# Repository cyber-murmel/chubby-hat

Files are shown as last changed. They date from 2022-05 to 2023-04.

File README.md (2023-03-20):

# Chubby Hat
A PCB that turns the [Colorlight 5A-75B](https://www.aliexpress.com/item/32728519290.html)
into an easy to use development platform for cheap.
This project ist based on [q3k/chubby75](https://github.com/q3k/chubby75/tree/master/5a-75b).

Read more on [ hackaday.io](https://hackaday.io/project/174032-chubby-hat).

## Directory Structure
| directory  | content |
|---|---|
| source | KiCad project directories |
| production | fabrication files (Gerber, BOM, placement) |
| exports | schematic and layout plots, board 3D model and renderings |
| datasheets | component datasheets |
| assets | board setups, component 3D models, logos |
| scripts | BOM export plugins, miscellaneous helper scripts for file conversion |
| hooks | git hooks, for example for automatic documentation export |

### Version 0.1.0

- USB to JTAG via STM32 or FTDI
- two 3x Pmod ports



### Version 0.2.0

- USB to JTAG via extra dev board or on-board RP2040
- three 2x Pmod ports

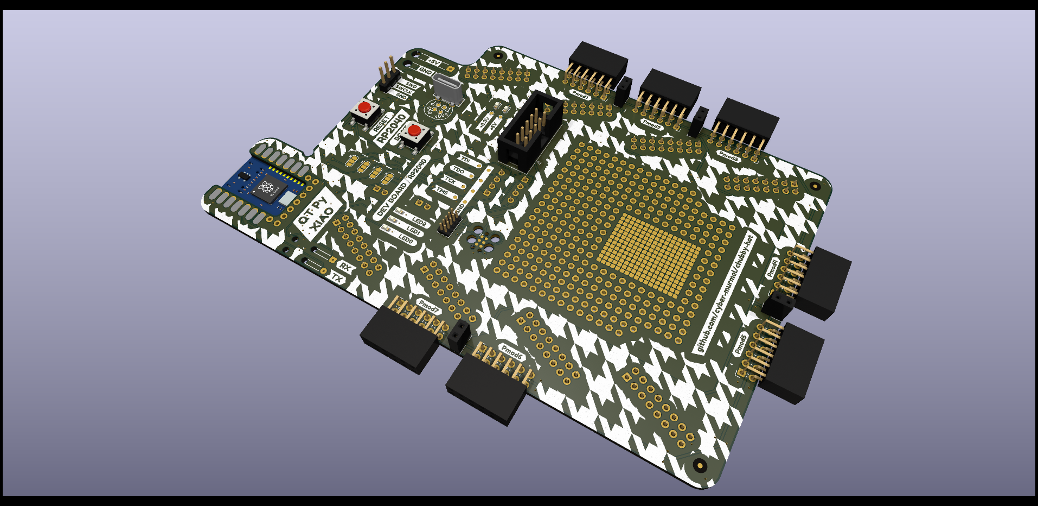
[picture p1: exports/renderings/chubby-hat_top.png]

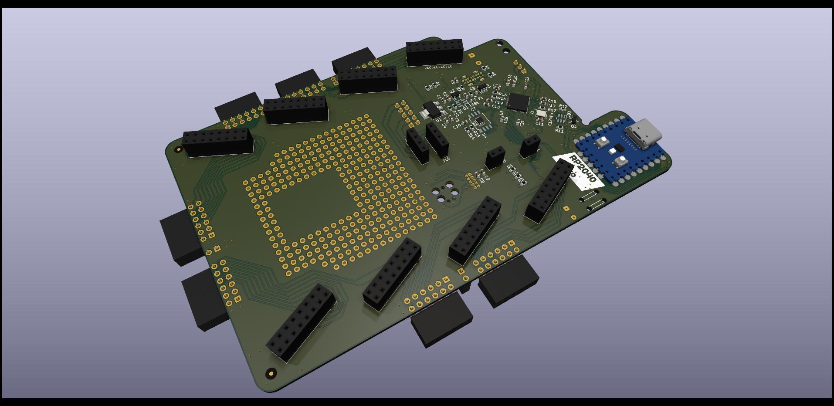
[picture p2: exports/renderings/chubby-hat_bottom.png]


## Automation
This repository contains a Makefile that automates PDF and Gerber export, as
well as PCB art pattern creation.

### Requirements
Apart from [KiCad 7](#kicad-version) this requires some additional software.

The Makefile calls a Python script that makes use of [sexptdata](https://pypi.org/project/sexpdata/) to parse KiCad files.
Install [Poetry](https://python-poetry.org/) and run `poetry shell` followed by `poetry install` in the root of this repositoryto set up a virtual environment with the required package(s). To re-enter this environment, simply run `poetry shell` in the root of this repository.

For PDF export you need to install [Poppler](https://poppler.freedesktop.org/).
Gerber export requires [zip](https://infozip.sourceforge.net/).
Pattern creation is implemented with [OpenSCAD](https://openscad.org/).

#### Nix(OS)
If you are using the Nix package manager, you can enter a development environment
with KiCad and all other software by running `nix-shell` in the root of this
repository.

### Export
To export all PDFs and Gerbers, simply run
```shell
make
```
PDFs and Gerbers are exported automatically when you `git commit`, if you have
[Git Hooks](#installing-git-hooks-optional) set up.

### Pattern
To recreate the pattern, first remove the pattern from the board and save it,
then run
```shell
make pattern
```
Add the new pattern graphic to the board.

### Installing Git Hooks (optional)
The [hooks](hooks) directory contains client-side [git hooks](https://git-scm.com/book/en/v2/Customizing-Git-Git-Hooks).
Currently only the pre-commit hook is used to automatically export plots.

To enable the hooks locally, run the following in the root of the repository.
```shell
git config core.hooksPath ./hooks
```

## KiCad Version
```
Version: 7.0.1, release build

Libraries:
	wxWidgets 3.2.2
	FreeType 2.12.1
	HarfBuzz 6.0.0
	FontConfig 2.14.0
	libcurl/7.87.0 OpenSSL/3.0.8 zlib/1.2.13 brotli/1.0.9 zstd/1.5.2 libidn2/2.3.2 libssh2/1.10.0 nghttp2/1.51.0

Platform: , 64 bit, Little endian, wxBase, , wayland

Build Info:
	Date: Jan  1 1980 00:00:00
	wxWidgets: 3.2.2 (wchar_t,wx containers) GTK+ 0.0
	Boost: 1.79.0
	OCC: 7.6.2
	Curl: 7.87.0
	ngspice: 37
	Compiler: GCC 12.2.0 with C++ ABI 1017

Build settings:
	KICAD_USE_EGL=ON
	KICAD_SPICE=ON
```

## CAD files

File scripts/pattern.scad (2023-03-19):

size = 2;
margin = 2;
dx = 170;
dy = 120;

edge = "";
mask = "";

module striped_square(size = 1, length = 1, num_stripes = 2) {
    color("teal")
        for(stripe = [1:num_stripes]) {
            if((stripe % 2) == 1) {
                polygon([[stripe-1, 0], [stripe,0], [0, stripe], [0,stripe-1]]*size/num_stripes);
            }
        }
    color("green")
        for(stripe = [num_stripes:length*num_stripes]) {
            if((stripe % 2) == 1) {
                polygon([[stripe-1, 0], [stripe,0], [stripe-num_stripes, num_stripes], [stripe-1-num_stripes,num_stripes]]*size/num_stripes);
            }
        }
    color("turquoise")
        for(stripe = [length*num_stripes:(length+1)*num_stripes]) {
            if((stripe % 2) == 1) {
                polygon([[length*num_stripes, stripe-length*num_stripes-1], [length*num_stripes,stripe-length*num_stripes], [stripe-num_stripes, num_stripes], [stripe-num_stripes-1,num_stripes]]*size/num_stripes);
            }
        }
}

module houndstooth(size = 1, dx = 2, dy = 2) {
    nx = ceil((dx/size) / 2);
    ny = ceil((dy/size) / 2);

    union() {
        for (y = [0: ny-1]) {
            translate(([0, y] * size * 2))
                striped_square(size, 2*nx, 2);
        }

        for (x = [0: nx-1]) {
            translate(
                ([x, 0] * size * 2)
              + ([1, 2*ny] * size)
            )
                mirror([1, 1])
                   striped_square(size, 2*ny, 2);
        }
    }
}

difference() {
    intersection() {
        translate([-25,-25]) {
            import(edge);
        }
        houndstooth(size, dx, dy);
    }
    offset(r=margin) {
        translate([-25,-25]) {
            import(mask);
        }
    }
}

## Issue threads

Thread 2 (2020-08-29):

Switch D+ and D- on STM32

cyber-murmel, 2020-08-29:
USB is connected the wrong way to the U3.

Closed 2020-08-30.

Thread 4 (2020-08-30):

Improve electrical safety

cyber-murmel, 2020-08-30:
Add [0.5A resettable fuse](https://lcsc.com/product-detail/PTC-Resettable-Fuses_TLC-Electronic-TLC-FSMD020_C261935.html) before reverse polarity protection.

Closed 2023-02-10.

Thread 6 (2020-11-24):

Gerbers

DatanoiseTV, 2020-11-24:
I've just acquired some of those cheap fpga boards. Could you generate gerbers for JLCPCB?
Also, does the PCB work? what about replacing the buffers on board? Unfortunately I cannot find the "chip" boards.

cyber-murmel, 2020-11-25:
Hey,

I will attach the gerbers to the [release tag](https://github.com/cyber-murmel/chubby-hat/releases/tag/v0.1). I should also have blank PCB left over from my order. If you are in Europe I could mail it to you.

Both debug adapters on the board work in principle
The STM32 running Versaloon is not very reliable, especially at higher TCK frequencies. @ktemkin suggested using [LUNA](https://github.com/greatscottgadgets/luna) instead of Versaloon. That's planned for the next version.
Currently I recommend using the FTDI.

I replaced half of the buffer drivers on my board by hand soldered wires.
The boards I designed didn't turn out so good. I suggest using @Disasm's [flex PCB](https://github.com/q3k/chubby75/issues/37#issuecomment-683424788) instead or replacing the buffers with [SN74CBT3245APW 8bit bidirectional FET switches](https://twitter.com/Claude1079/status/1231194849350647808)

cyber-murmel, 2020-11-25:
Ther Gerbers are now [here](https://github.com/cyber-murmel/chubby-hat/releases/download/v0.1/chubby.hat.gbr.zip)

PS regarding whether the board works:
The JTAG signals are also connected to standard JTAG headers, so you can still use the hat a breakout board together with a standalone debugger adapter, if the onboard adapters don't work.

DatanoiseTV, 2020-11-27:
@cyber-murmel Thank you. I'm im Berlin. If you have a spare board, I'd be happy to get it :) I will try to source a FT2232 then. Otherwise I have a FT2232-MINI somewhere

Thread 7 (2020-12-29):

Switchable in/outs and pmod ports

DoctorMikeReddy, 2020-12-29:
As you’ve hard wired some of the outputs to be inputs - mentioned in #6 - do you need to have a template in the firmware to stop the FPGA trying to output on those lines? Presumably, you need to replace the stock firmware? Also, why are there only 7 pmod ports, when there are 8 hub75 outputs? What’s is the eighth one used for? Could one be used, with replacement buffer chips - from a thread on chubby75 - to allow switchable IO ports? So, all the ports could be selectable in/out ports?

Apologies for all the questions

cyber-murmel, 2020-12-31:
The modification turns output-only ports into IO ports - i.e. input and output are **both** possible.

The HUB75 connectors share some signals. There are only 56 individual signals in total. This results in the 7 Pmod connectors.

The chubby hat currently doesn't enable replacing the stock gateware (micro controllers have firmware; FPGAs have gateware).
When uploading gateware via JTAG, it's placed in the volatile configuration registers of the FPGA. If then power is turned off and on again, the FPGA automatically loads the stock gateware from the on-board SPI flash.

As mentioned [here](https://github.com/cyber-murmel/chubby-hat/issues/6#issuecomment-733767319) it's suggested to replace the unidirectional buffers with [SN74CBT3245APW 8bit bidirectional FET switches](https://twitter.com/Claude1079/status/1231194849350647808)

Which pin is used as in or output will be determined by the gateware.

I hope this answers your questions, If something still remains unclear, feel free to follow up :-)

DoctorMikeReddy, 2020-12-31:
Not SN74CBT3245APW with the 5v rail diode hack?

As per:  https://twitter.com/Claude1079/status/1231194849350647808 and https://github.com/q3k/chubby75/issues/37

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

DoctorMikeReddy, 2020-12-31:
Wasn’t aware the base FW and microprocessor hadn’t been hacked yet. I’ll have a look at this

cyber-murmel, 2021-01-01:
There is no microprocessor on the colorlight. Only an FPGA, configuration flash, Ethernet PHYs and RAM.

Or are you referring to the original gateware that implements a kind of microprocessor on the FPGA?

cyber-murmel, 2021-12-31:
For later reference
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

cyber-murmel, 2021-12-31:
maybe SN74CBT3345PWR is suitable as well. only difference is one more OE pin.

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

https://datasheet.lcsc.com/lcsc/1809172014_Texas-Instruments-SN74CBT3245APWR_C7145.pdf
https://datasheet.lcsc.com/lcsc/1806112030_Texas-Instruments-SN74CBT3345PWR_C201963.pdf

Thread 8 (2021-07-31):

Anyone tried upgrading the RAM from 2 x 1M to higher capacity ??

stanleyseow, 2021-07-31:
Good work on the chubby-hat, read about this on hackaday.io.

Unrelated to chubby-hat, did anyone tried upgrading 2 x 1M RAM to a higher capacities ??

I was reading the ESMT datasheets but have not much experience with FPGA memory.

Thanks

( pls close this issue if it is unrelated )

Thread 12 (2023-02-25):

Find solution for +3.3V on Pmod

cyber-murmel, 2023-02-25:
Currently the +3.3V ports of the Pmod would be unpowered, if no LDO is installed on the Chubby Hat.

One option is to get power from the Colorlight. This could happen through a jumper from VDD to +3.3V.

Another option is getting power from the module soldered to the Chubby Hat.

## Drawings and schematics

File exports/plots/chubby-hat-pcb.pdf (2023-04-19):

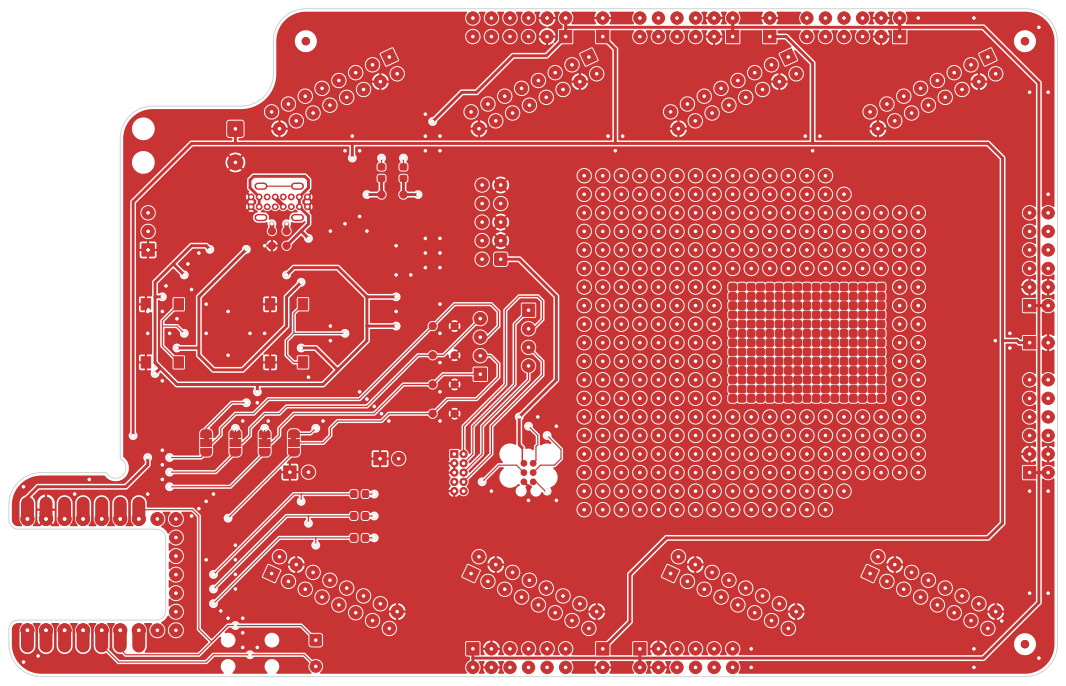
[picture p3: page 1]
D Date: 2023-01-29 KiCad; kicad-cli; 7.0.1 Size: A4; Rev: 0.2.2

Id: 1/1 Title: Chubby Hat File: chubby-hat.kicad_pcb Sheet: github.com/cyber-murmel/chubby-hat

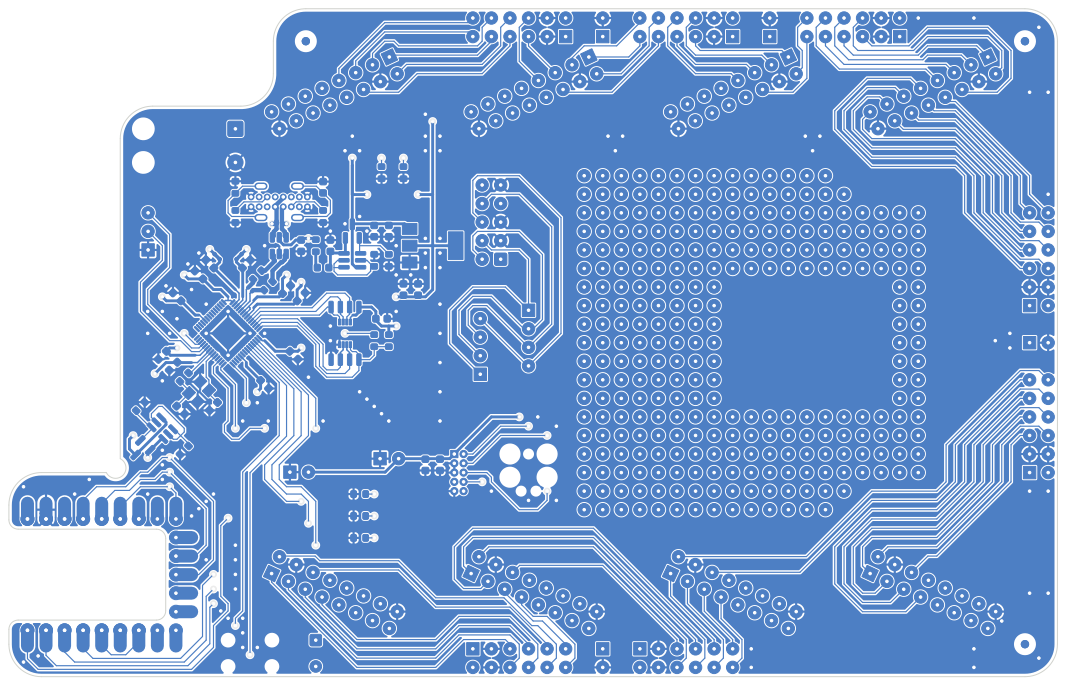
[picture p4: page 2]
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

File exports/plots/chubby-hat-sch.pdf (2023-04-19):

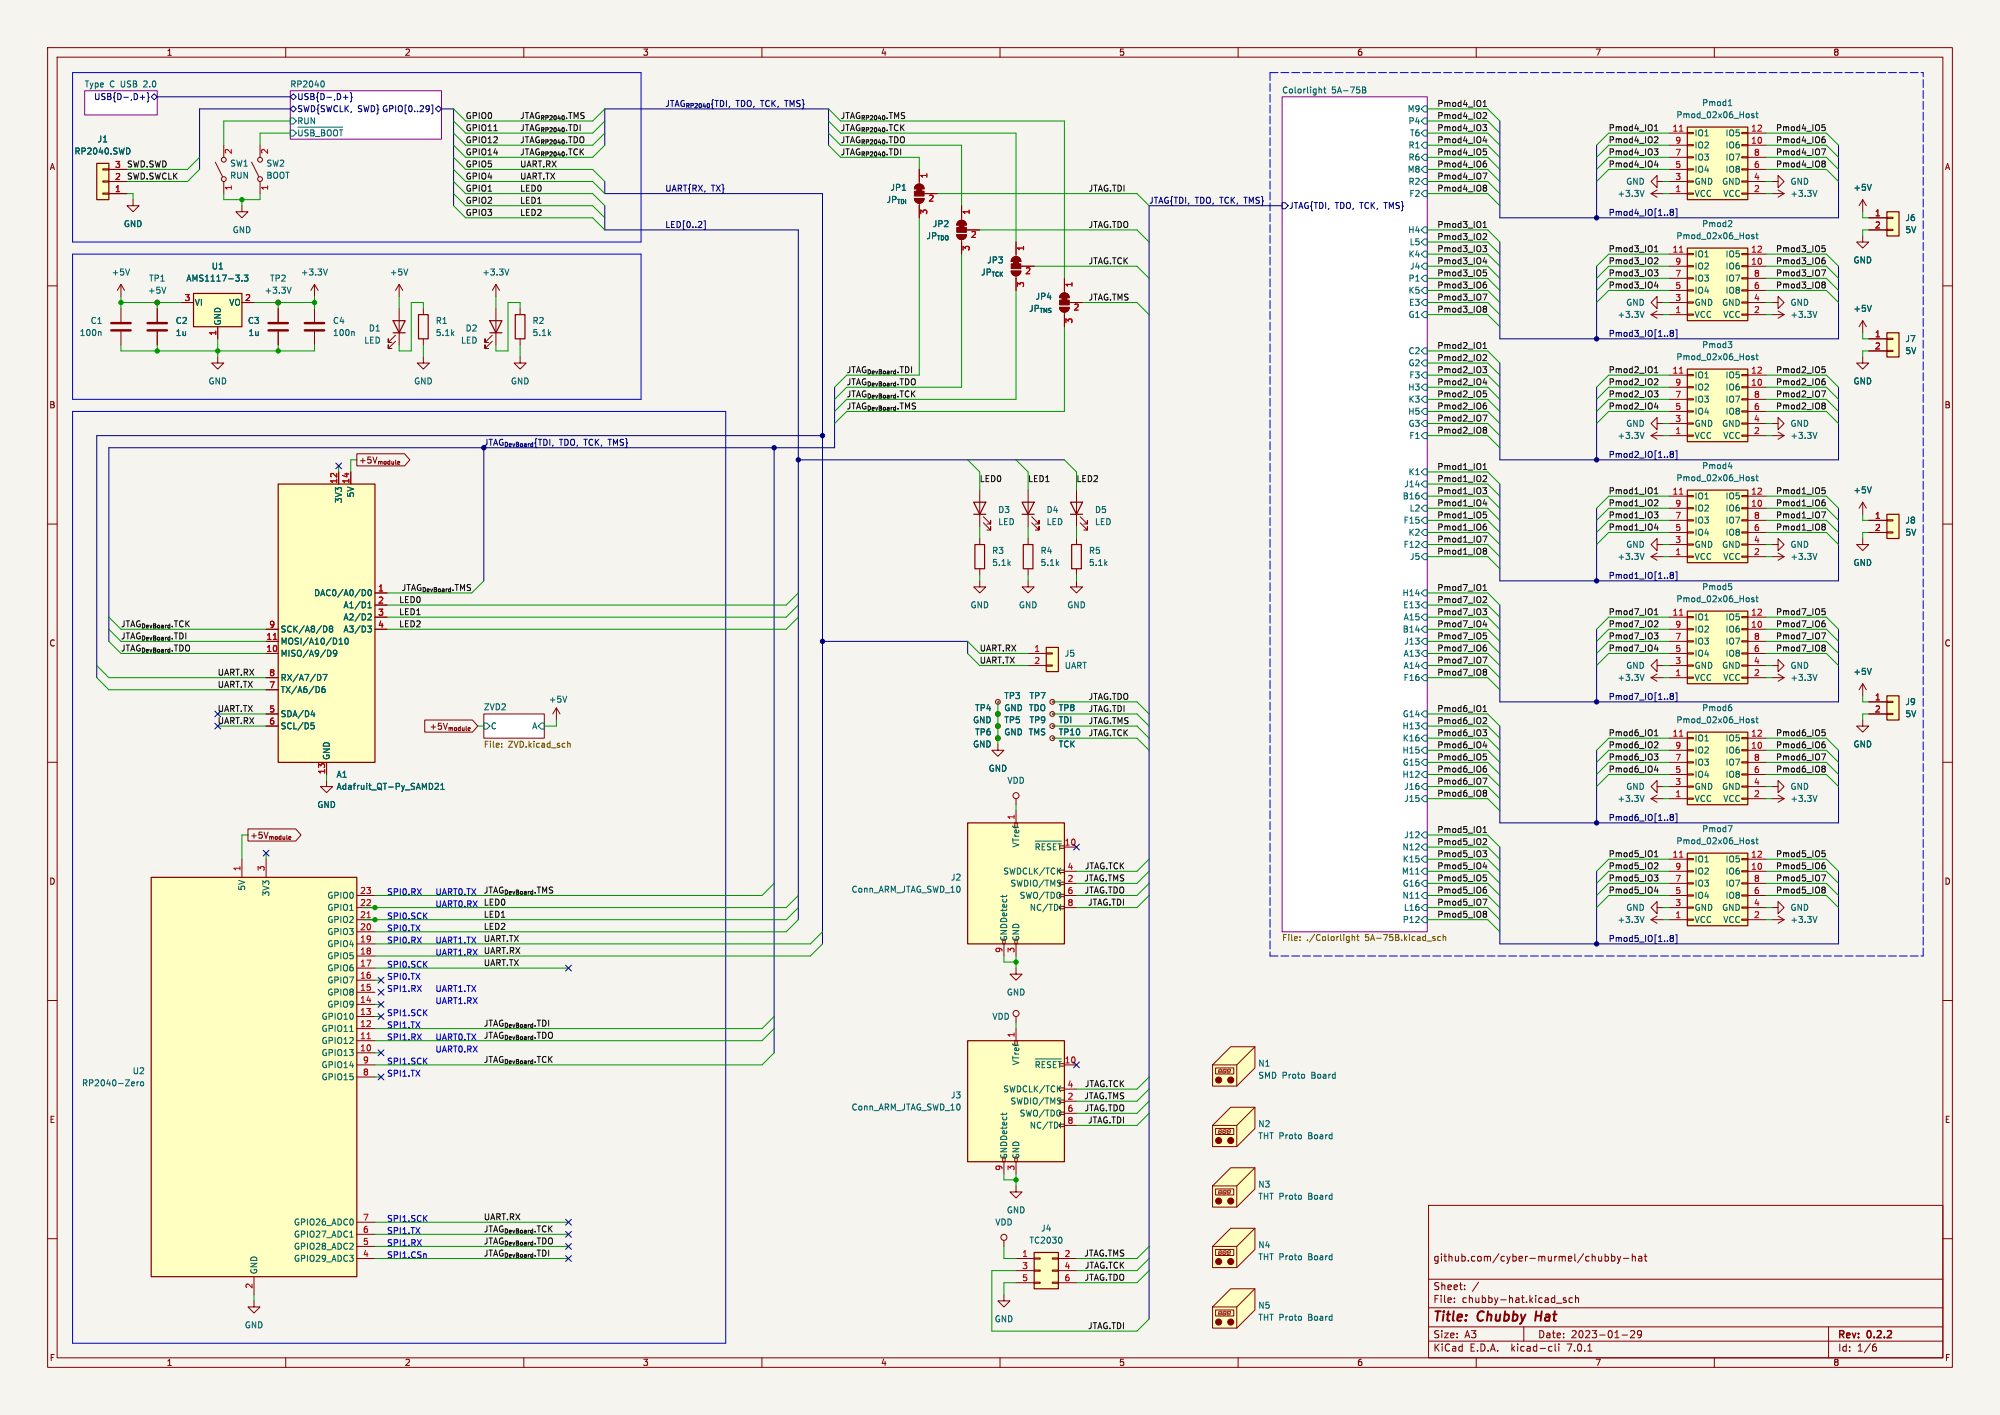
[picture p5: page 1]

USB{D-,D+}
SWD{SWCLK, SWD} RUN

JTAG_{RP2040}{TDI, TDO, TCK, TMS}

JTAG{TDI, TDO, TCK, TMS}

Pmod5_IO8 Pmod7_IO4 UART.RX UART.TX UART.TX

3 SWDCLK/TCK 4 SWO/TDO 6 NC/TDI 8 GNDDetect 9

JTAG_{DevBoard}.TDI
JTAG.TDI JTAG_{DevBoard}.TDO

N1SMD Proto Board
N4 THT Proto Board N2 THT Proto Board N5 THT Proto Board

Id: 1/6 Title: Chubby Hat File: chubby-hat.kicad_sch Sheet: / github.com/cyber-murmel/chubby-hat

JTAG.TCK
JTAG.TDI JTAG.TDO

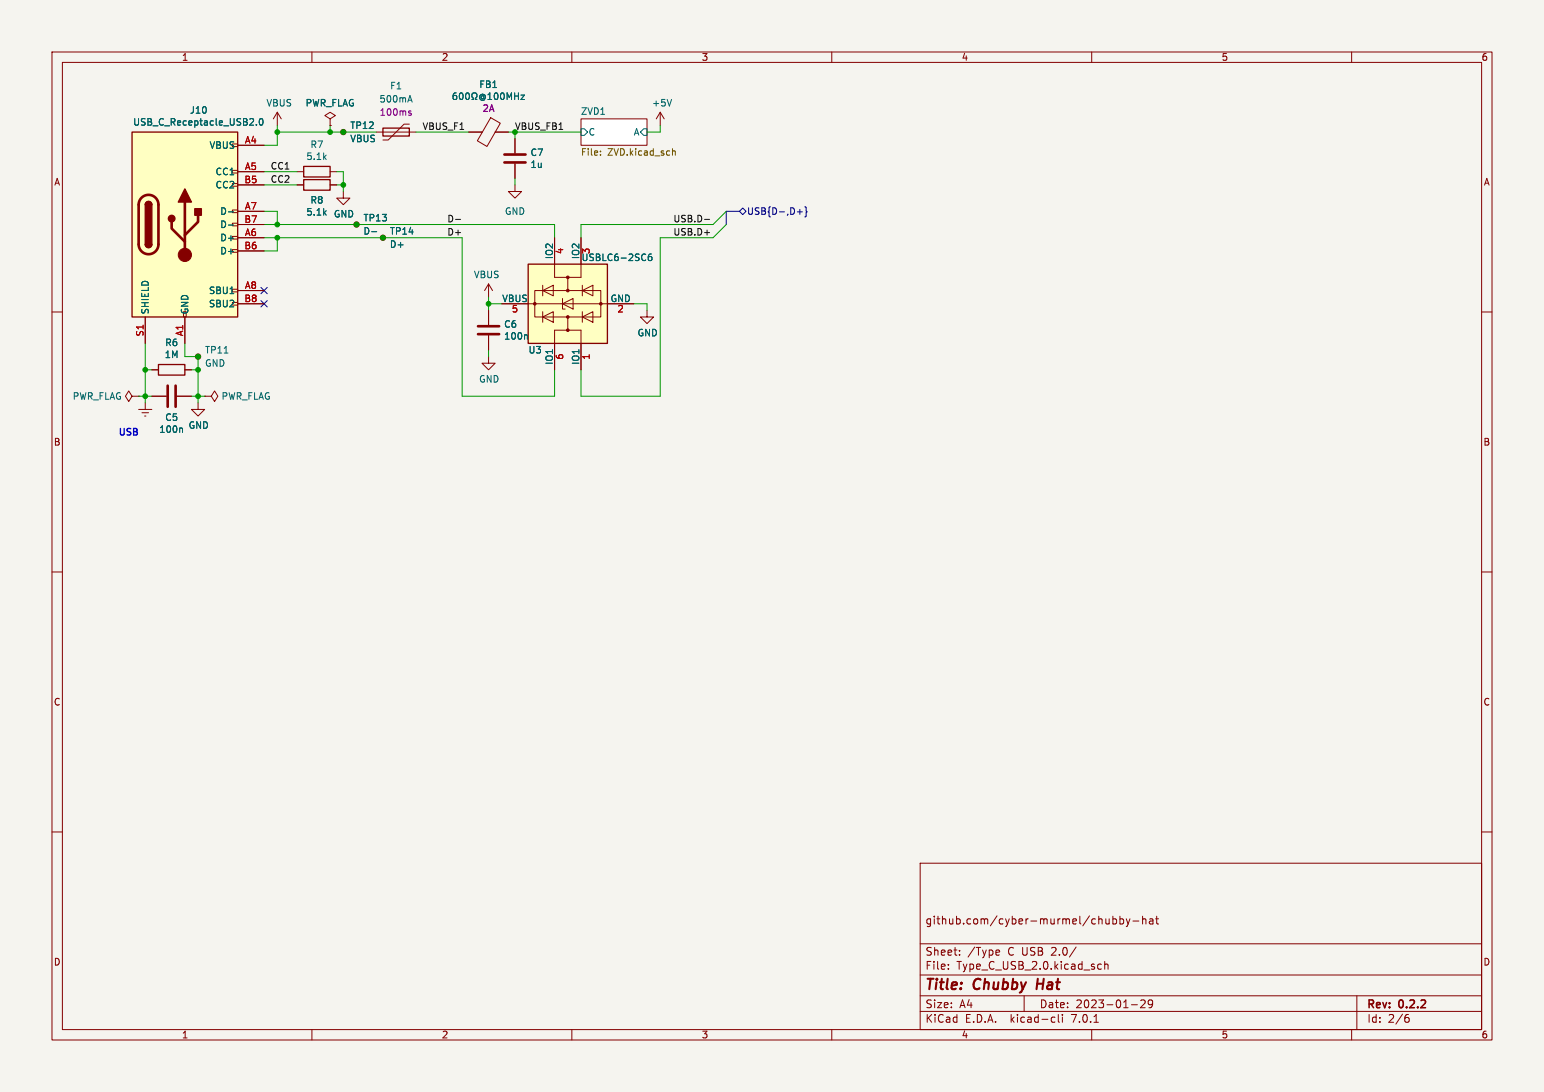
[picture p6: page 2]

Id: 2/6 Title: Chubby Hat File: Type_C_USB_2.0.kicad_sch Sheet: /Type C USB 2.0/ github.com/cyber-murmel/chubby-hat

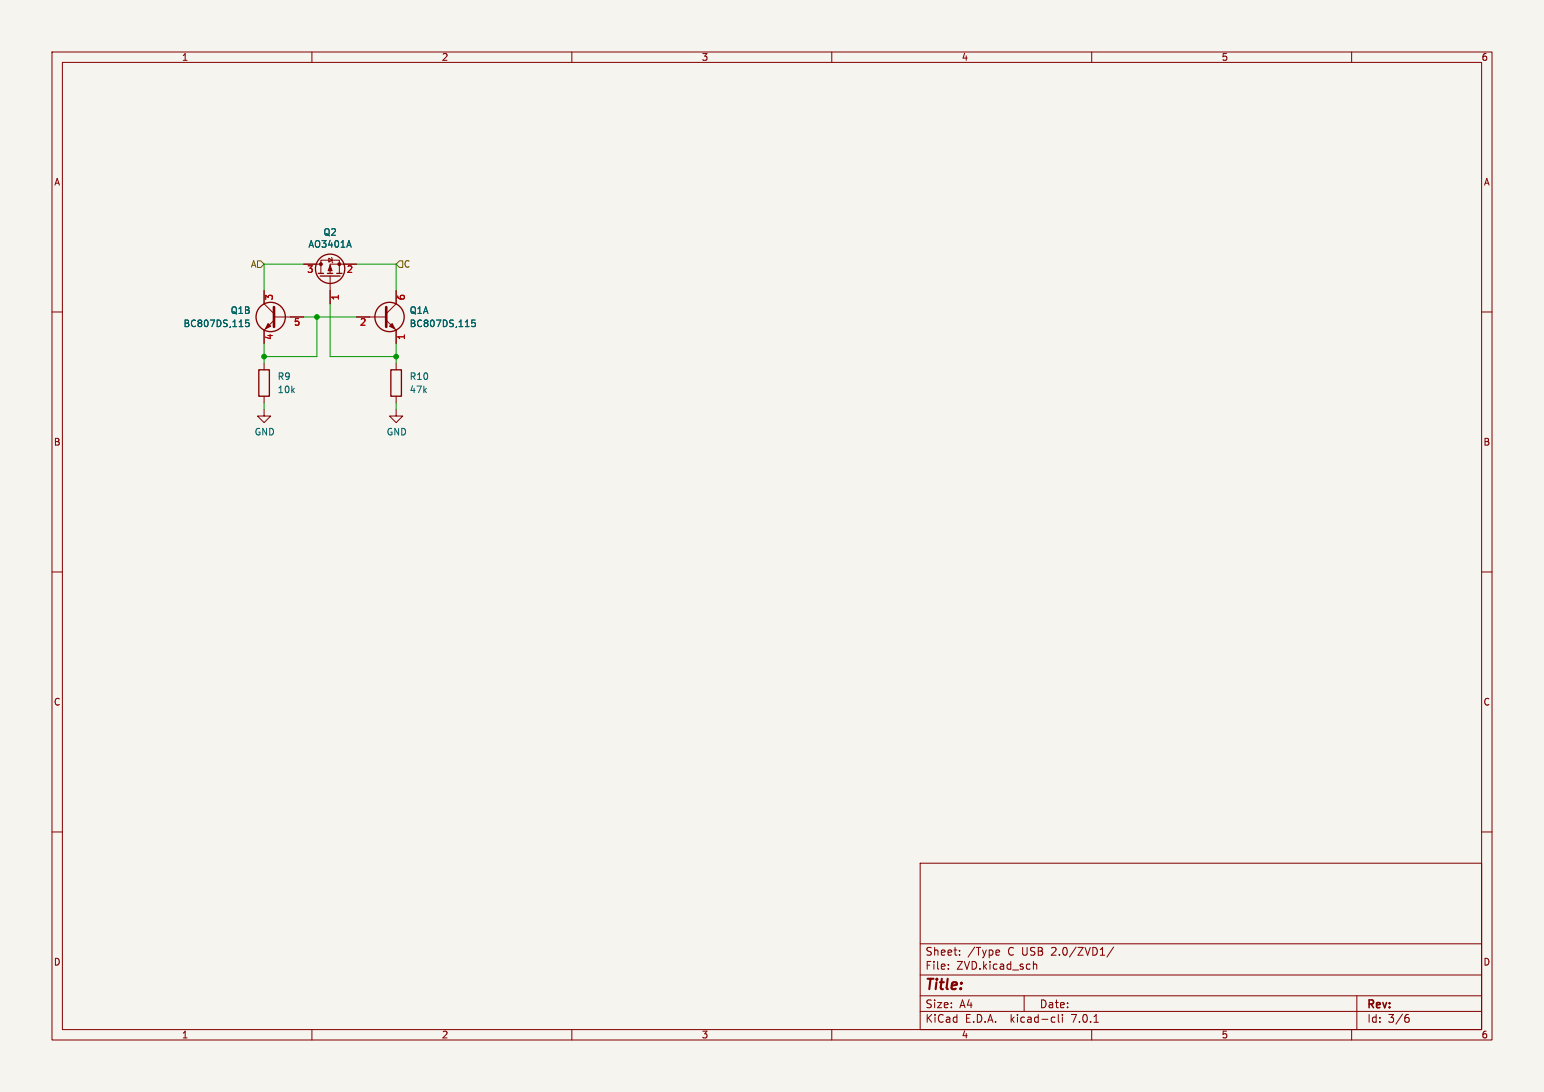
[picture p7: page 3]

Id: 3/6 Title: File: ZVD.kicad_sch Sheet: /Type C USB 2.0/ZVD1/

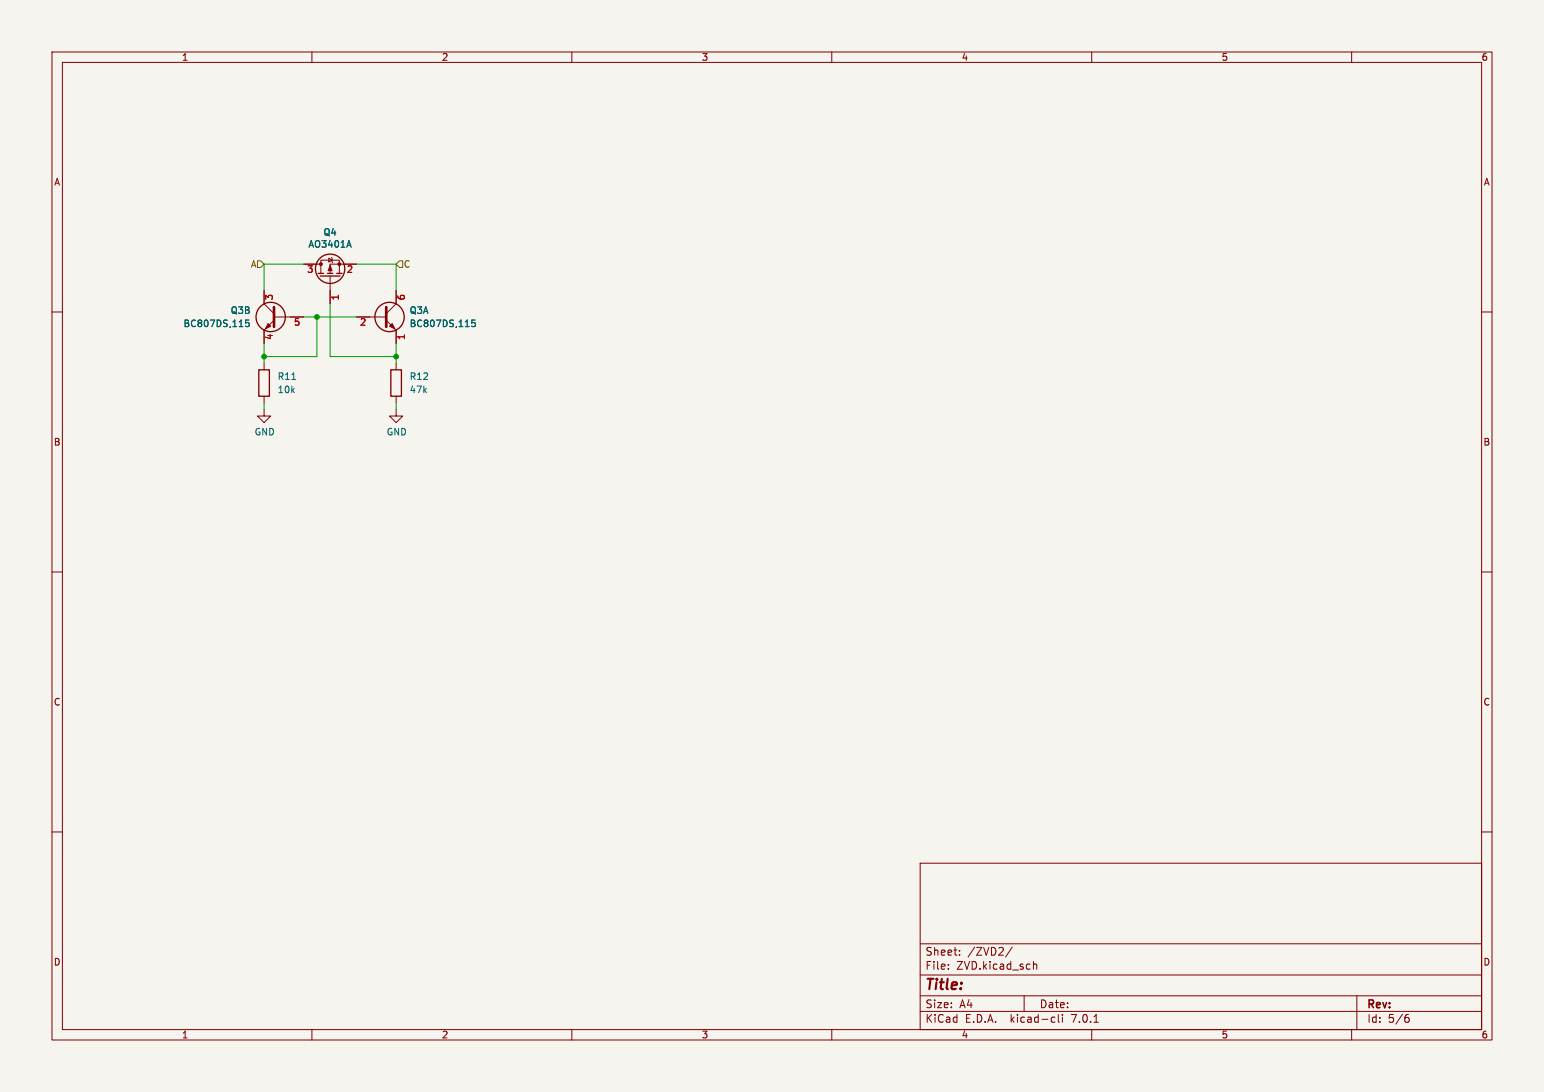
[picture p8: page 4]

Id: 5/6 Title: File: ZVD.kicad_sch Sheet: /ZVD2/

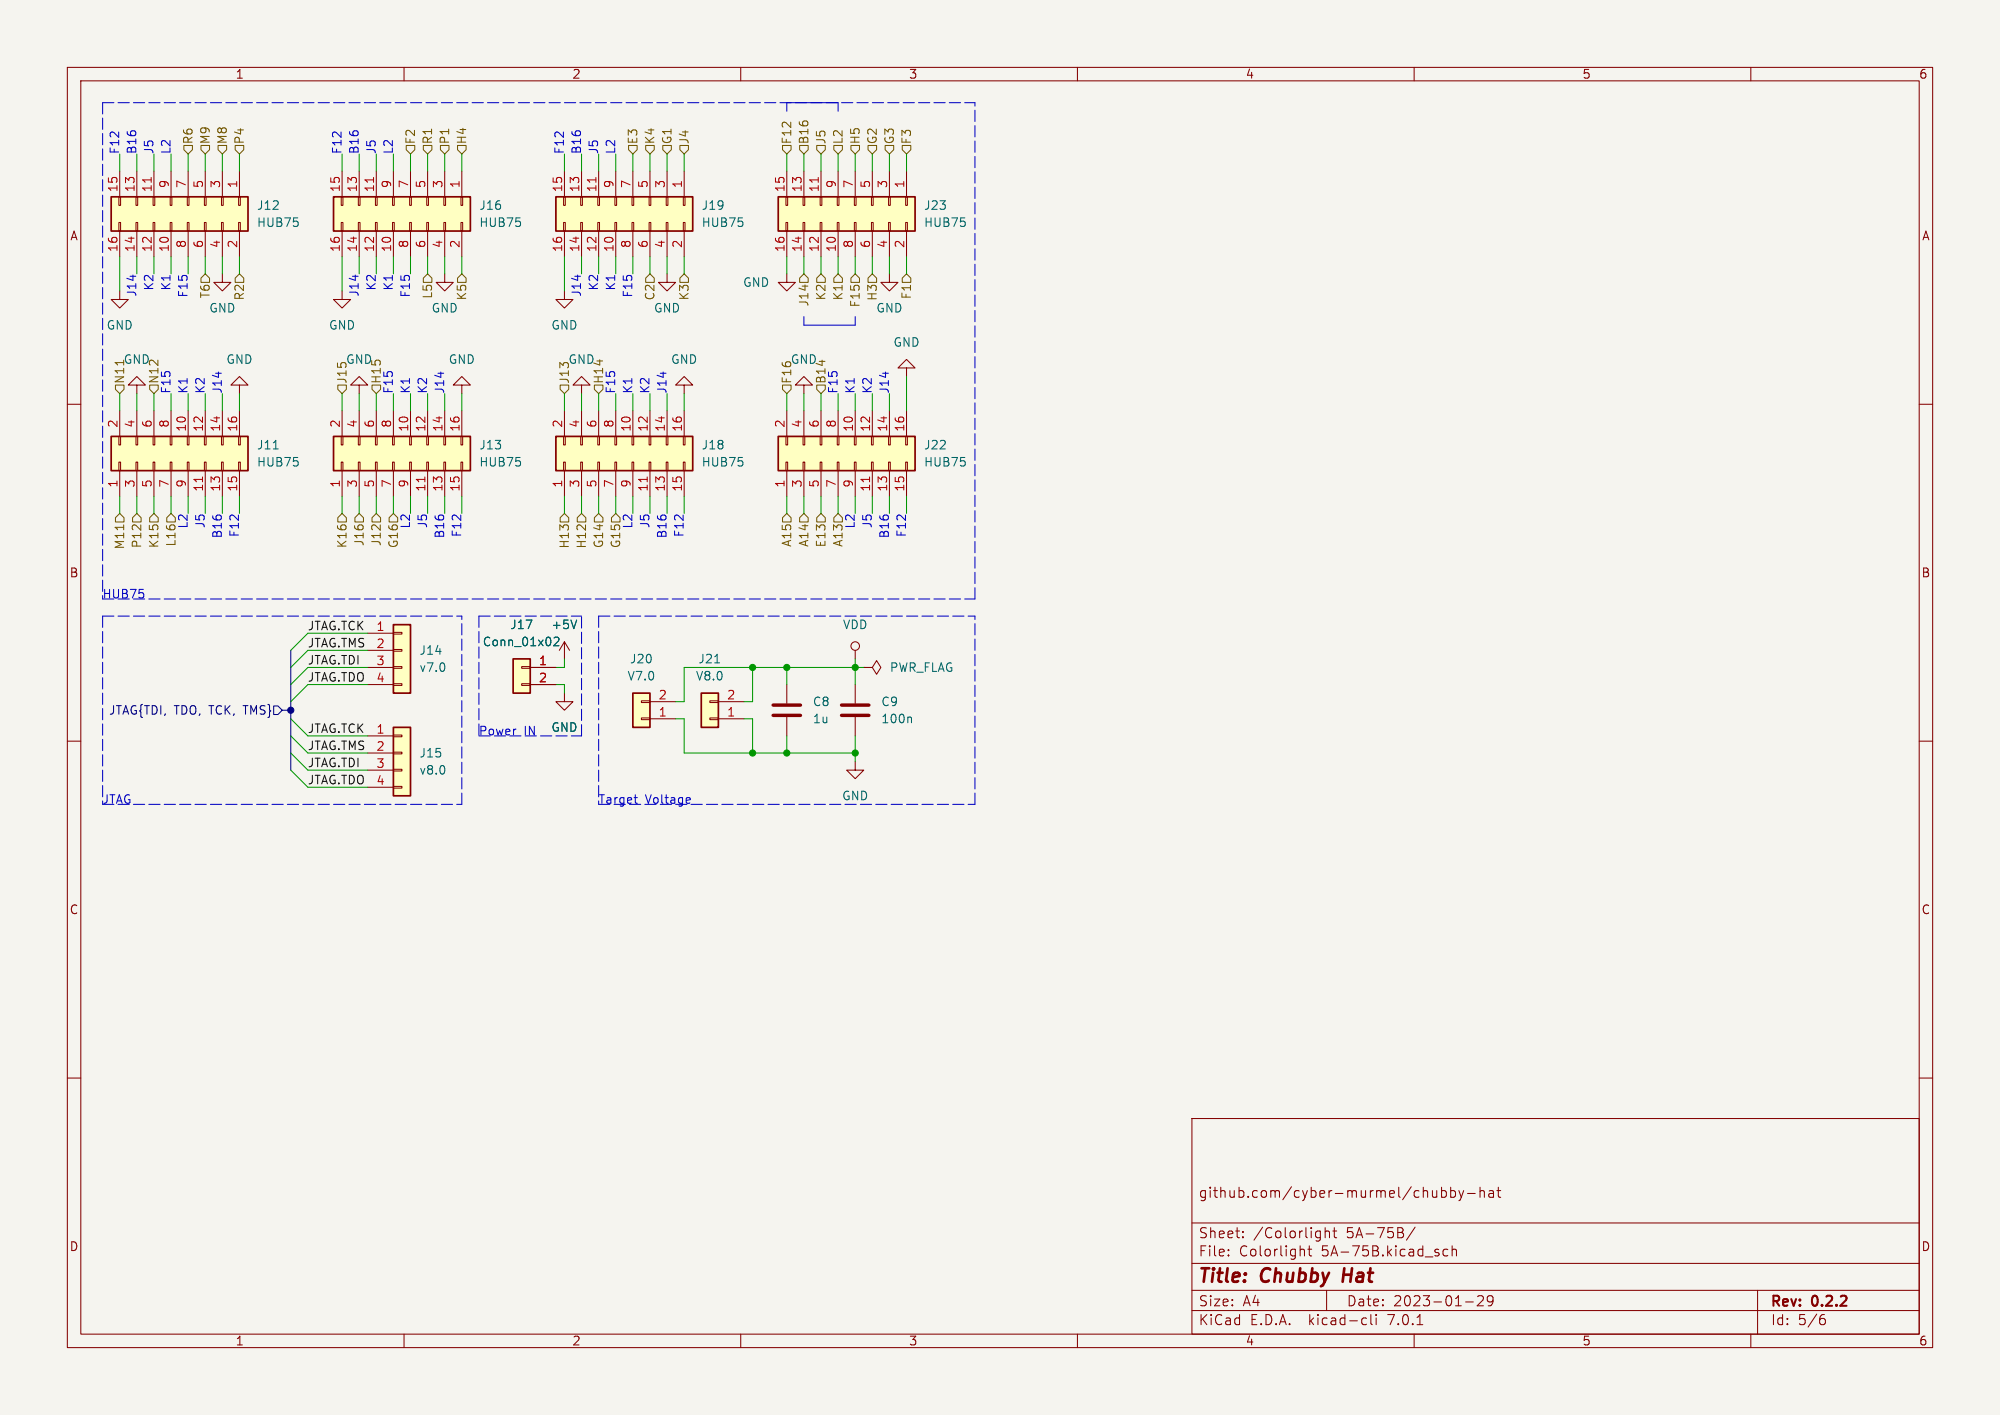
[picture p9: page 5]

JTAG.TCK
JTAG.TDI JTAG.TMS

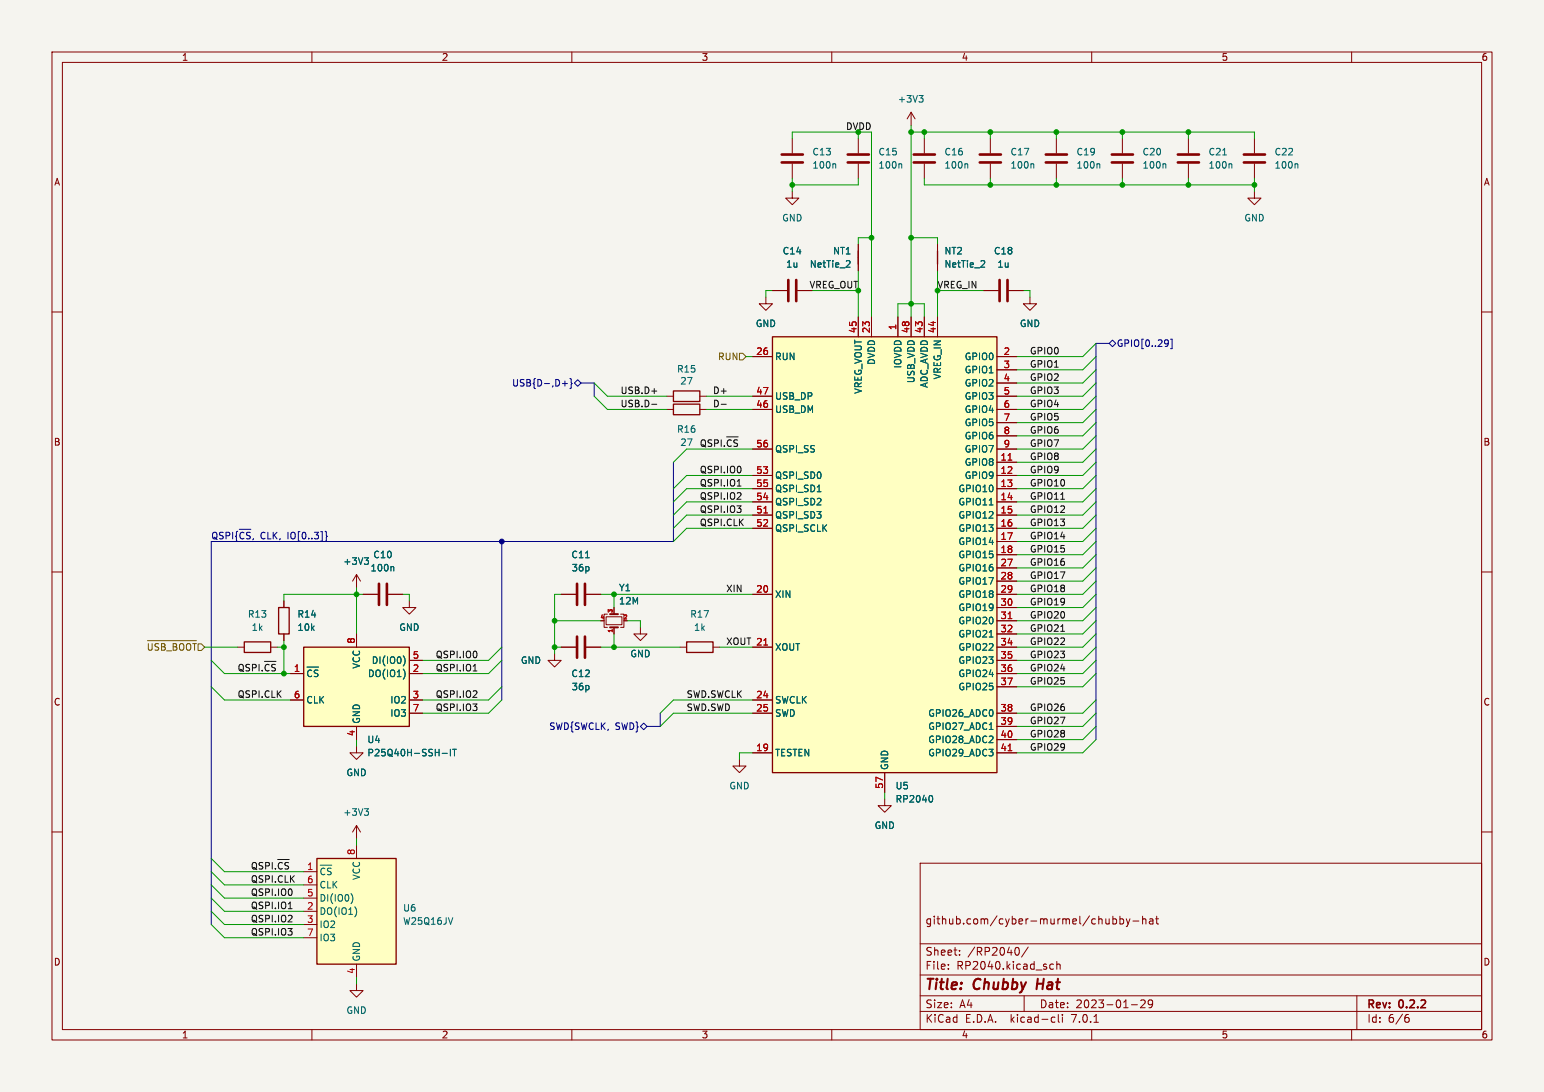
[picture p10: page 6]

1 GPIO8 11 GPIO9 12 GPIO10 13 GPIO11 14 GPIO12 15 GPIO13 16 GPIO14 17 GPIO15 18 TESTEN 19 GPIO0 2 XIN 20 XOUT 21 DVDD 23 SWCLK 24 SWD 25 RUN 26 GPIO16 27 GPIO17 28 GPIO18 29 GPIO1 3 GPIO19 30 GPIO20 31 GPIO21 32 GPIO22 34 GPIO23 35 GPIO24 36 GPIO25 37 GPIO26_ADC0 38 GPIO27_ADC1 39 GPIO2 4 GPIO28_ADC2 40 GPIO29_ADC3 41 ADC_AVDD 43 VREG_IN 44 VREG_VOUT 45 USB_DM 46 USB_DP 47 USB_VDD 48 GPIO3 5 QSPI_SD3 51 QSPI_SCLK 52 QSPI_SD0 53 QSPI_SD2 54 QSPI_SD1 55 QSPI_SS 56 GND 57 GPIO4 6 GPIO5 7 GPIO6 8 GPIO7 9 U5 RP2040 C10

1 GPIO8 11 GPIO9 12 GPIO10 13 GPIO11 14 GPIO12 15 GPIO13 16 GPIO14 17 GPIO15 18 TESTEN 19 GPIO0 2 XIN 20 XOUT 21 DVDD 23 SWCLK 24 SWD 25 RUN 26 GPIO16 27 GPIO17 28 GPIO18 29 GPIO1 3 GPIO19 30 GPIO20 31 GPIO21 32 GPIO22 34 GPIO23 35 GPIO24 36 GPIO25 37 GPIO26_ADC0 38 GPIO27_ADC1 39 GPIO2 4 GPIO28_ADC2 40 GPIO29_ADC3 41 ADC_AVDD 43 VREG_IN 44 VREG_VOUT 45 USB_DM 46 USB_DP 47 USB_VDD 48 GPIO3 5 QSPI_SD3 51 QSPI_SCLK 52 QSPI_SD0 53 QSPI_SD2 54 QSPI_SD1 55 QSPI_SS 56 GND 57 GPIO4 6 GPIO5 7 GPIO6 8 GPIO7 9 GND GND

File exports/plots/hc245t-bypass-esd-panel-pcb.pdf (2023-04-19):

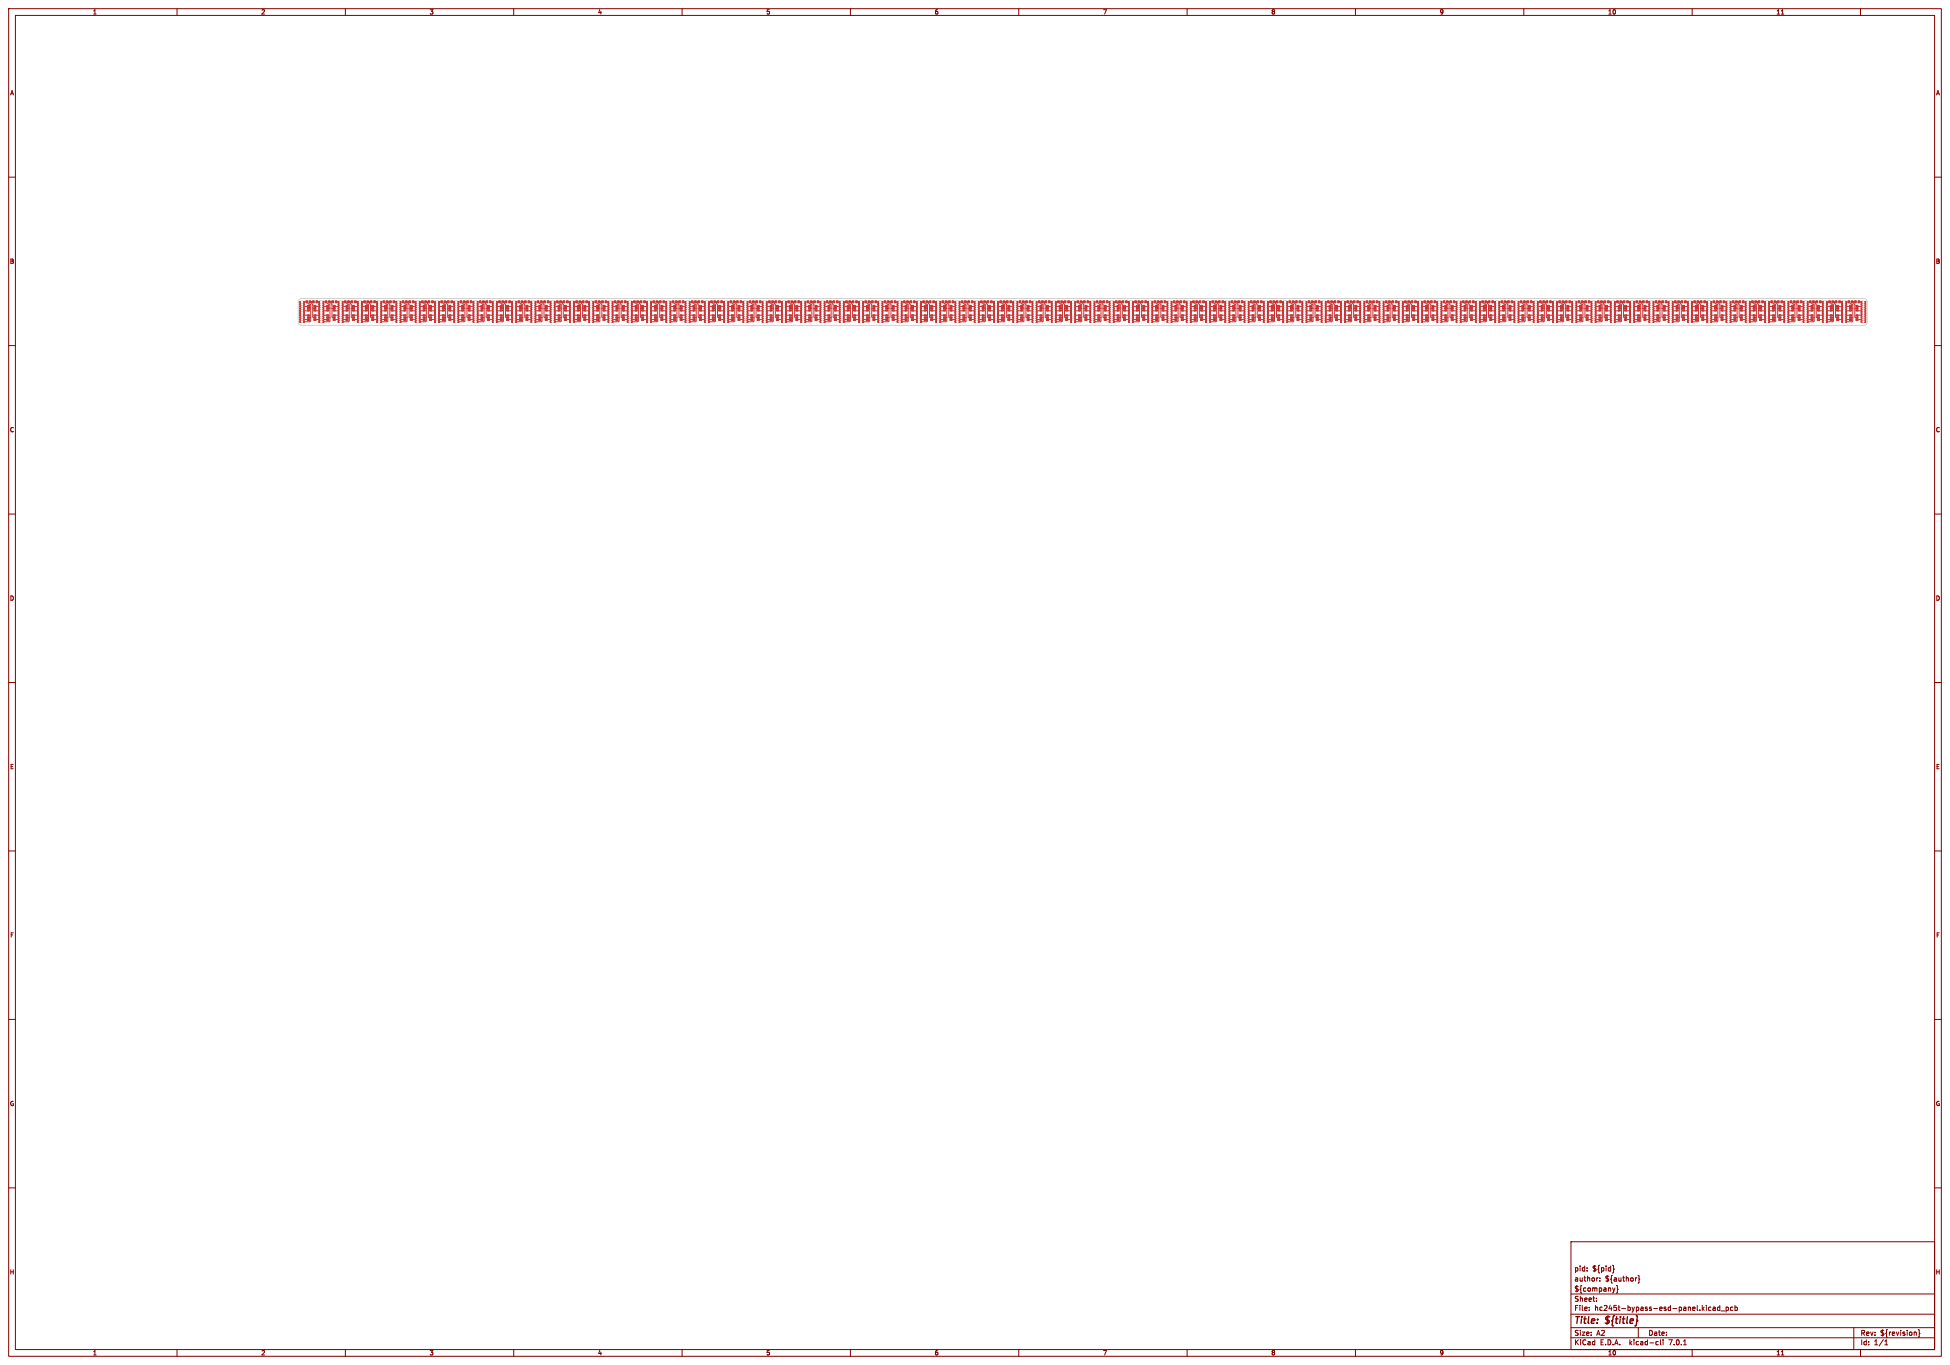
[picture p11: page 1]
H Date: KiCad; kicad-cli; 7.0.1 Size: A2; Rev:; ${revision}; Id: 1/1 Title: ${title} File:; hc245t-bypass-esd-panel.kicad_pcb Sheet: ${company} author: ${author}; pid: ${pid}

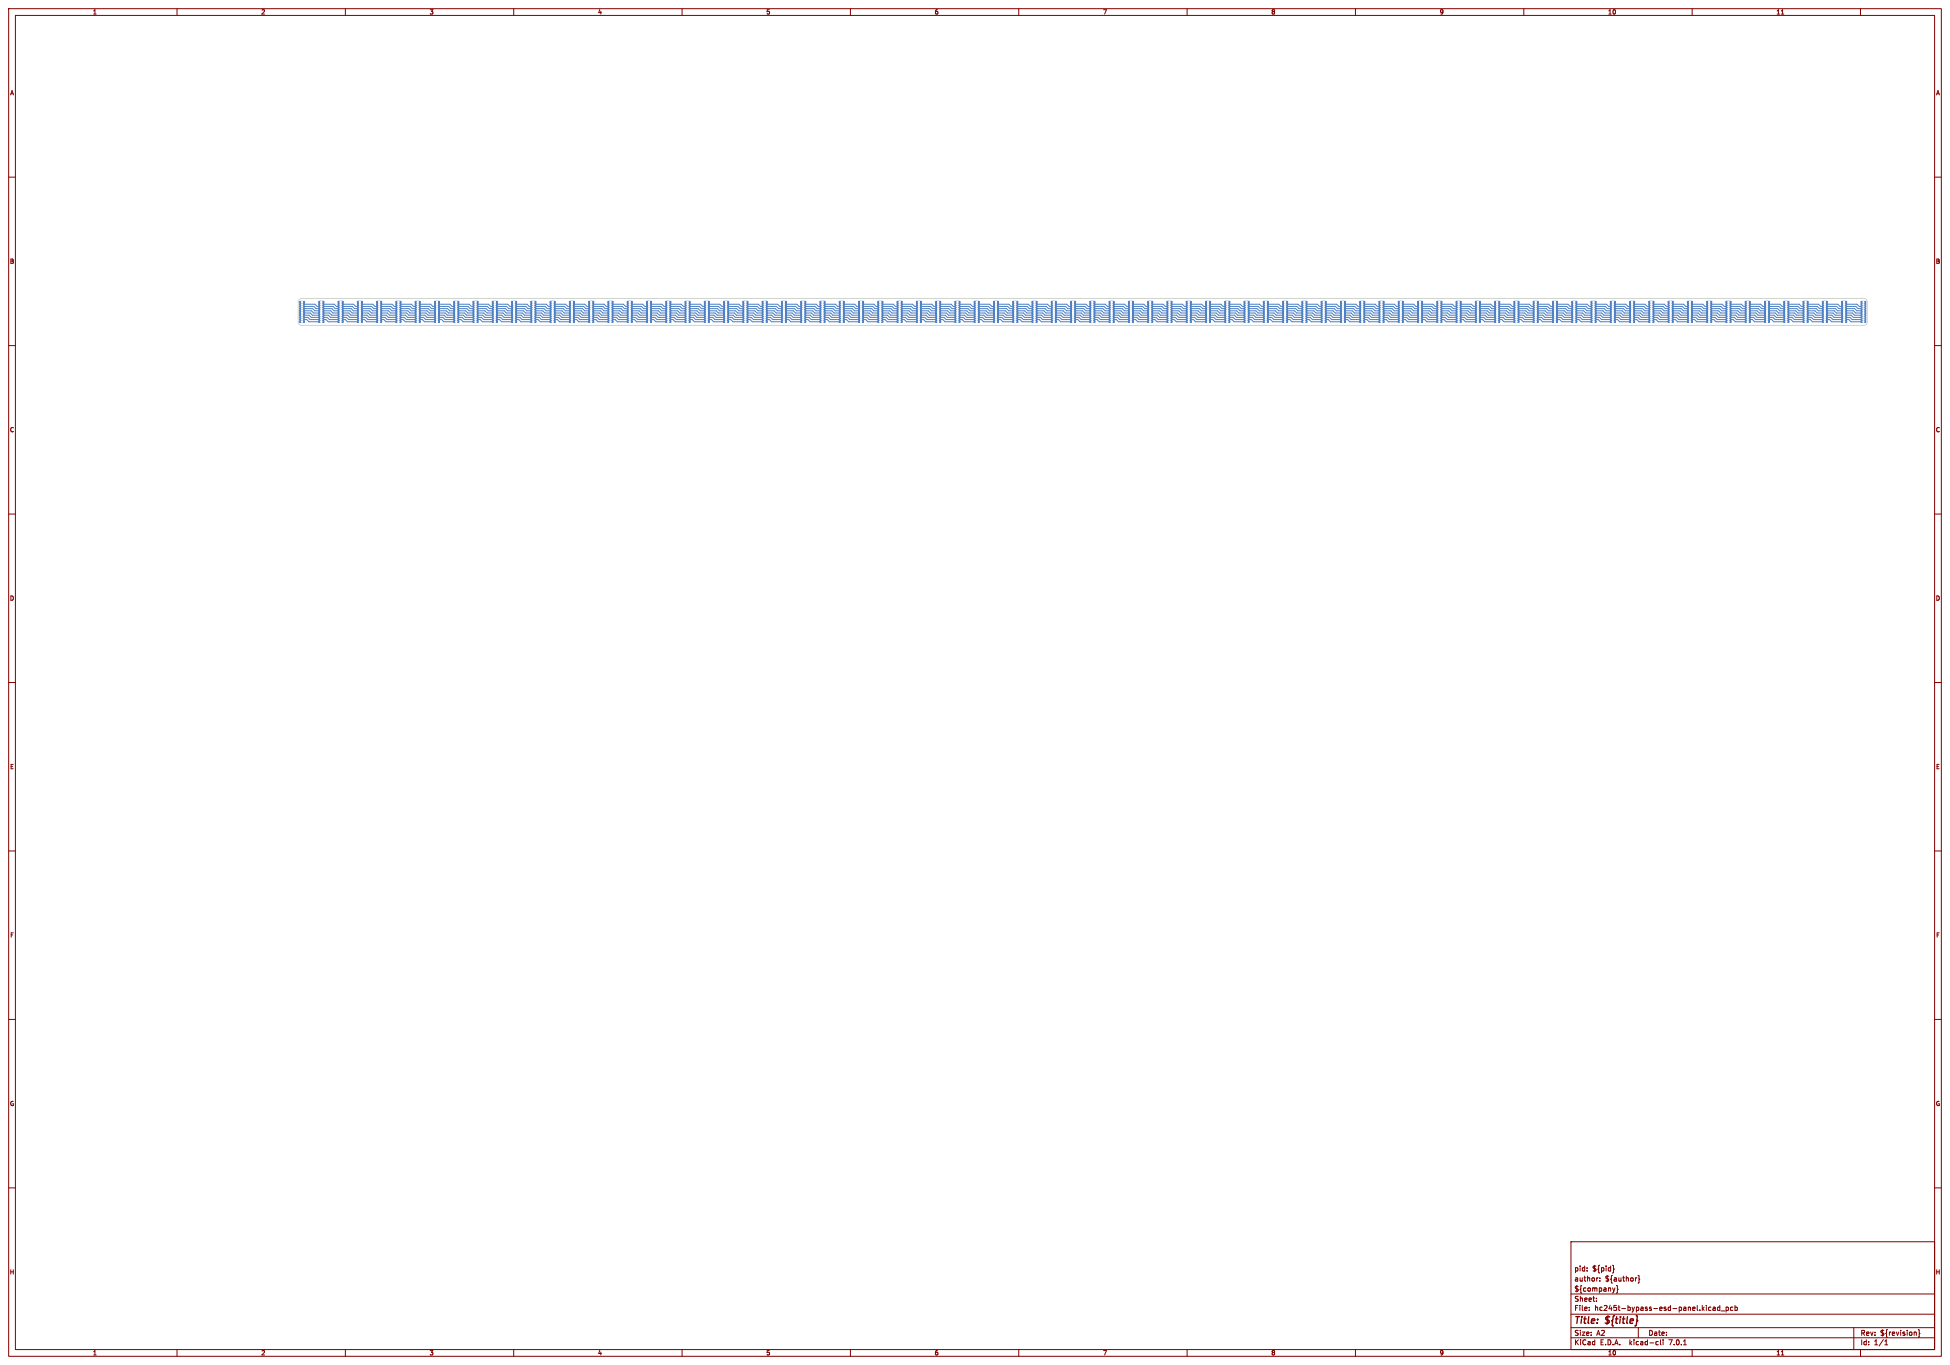
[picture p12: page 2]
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

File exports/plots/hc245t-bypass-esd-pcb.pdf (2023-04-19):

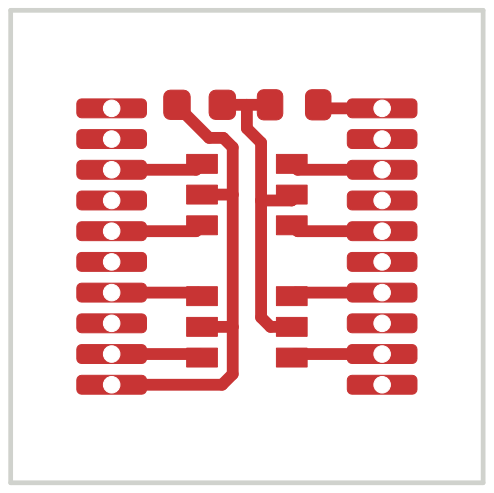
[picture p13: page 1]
D Date: KiCad; kicad-cli; 7.0.1 Size: A4; Rev: 0.1.0; File:; hc245t-bypass-esd.kicad_pcb Sheet: Company; Name; author: Author

pid: project id

Id: 1/1 Title: Project Name

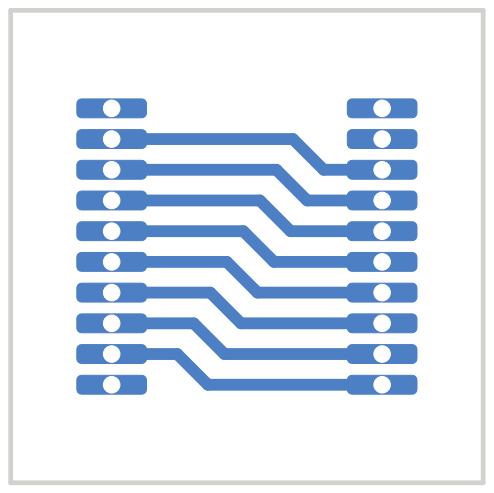
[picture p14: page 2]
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

pid: project id

Id: 1/1 Title: Project Name

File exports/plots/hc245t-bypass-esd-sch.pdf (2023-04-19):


pid: project id GND

Id: 1/1 Title: Project Name

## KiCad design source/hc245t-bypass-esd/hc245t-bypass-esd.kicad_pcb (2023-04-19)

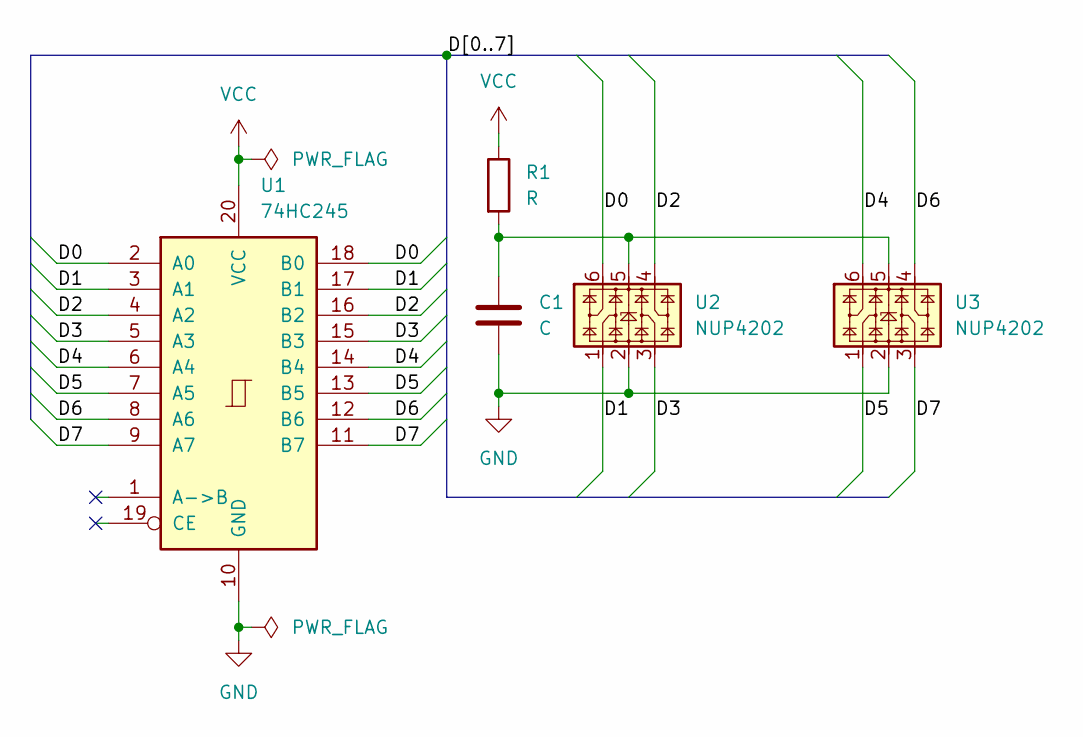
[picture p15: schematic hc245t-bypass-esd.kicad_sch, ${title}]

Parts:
C1: C; C_0402_1005Metric
R1: R; R_0402_1005Metric
U1: 74HC245; TSSOP-20_4.4x6.5mm_P0.65mm
U2, U3: NUP4202; SOT-363_SC-70-6

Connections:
/D0: U1.2 (A0), U1.18 (B0), U2.6
/D1: U1.3 (A1), U1.17 (B1), U2.1
/D2: U1.4 (A2), U1.16 (B2), U2.4
/D3: U1.5 (A3), U1.15 (B3), U2.3
/D4: U1.6 (A4), U1.14 (B4), U3.6
/D5: U1.7 (A5), U1.13 (B5), U3.1
/D6: U1.8 (A6), U1.12 (B6), U3.4
/D7: U1.9 (A7), U1.11 (B7), U3.3
GND: C1.2, U1.10 (GND), U2.2, U3.2
unnamed: C1.1, R1.2, U2.5, U3.5
VCC: R1.1, U1.20 (VCC)

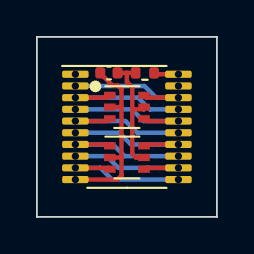
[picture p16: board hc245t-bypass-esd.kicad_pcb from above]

Board: 2 copper layers, 10.0 x 10.0 mm, 5 parts (0 on the bottom side), 11 nets.

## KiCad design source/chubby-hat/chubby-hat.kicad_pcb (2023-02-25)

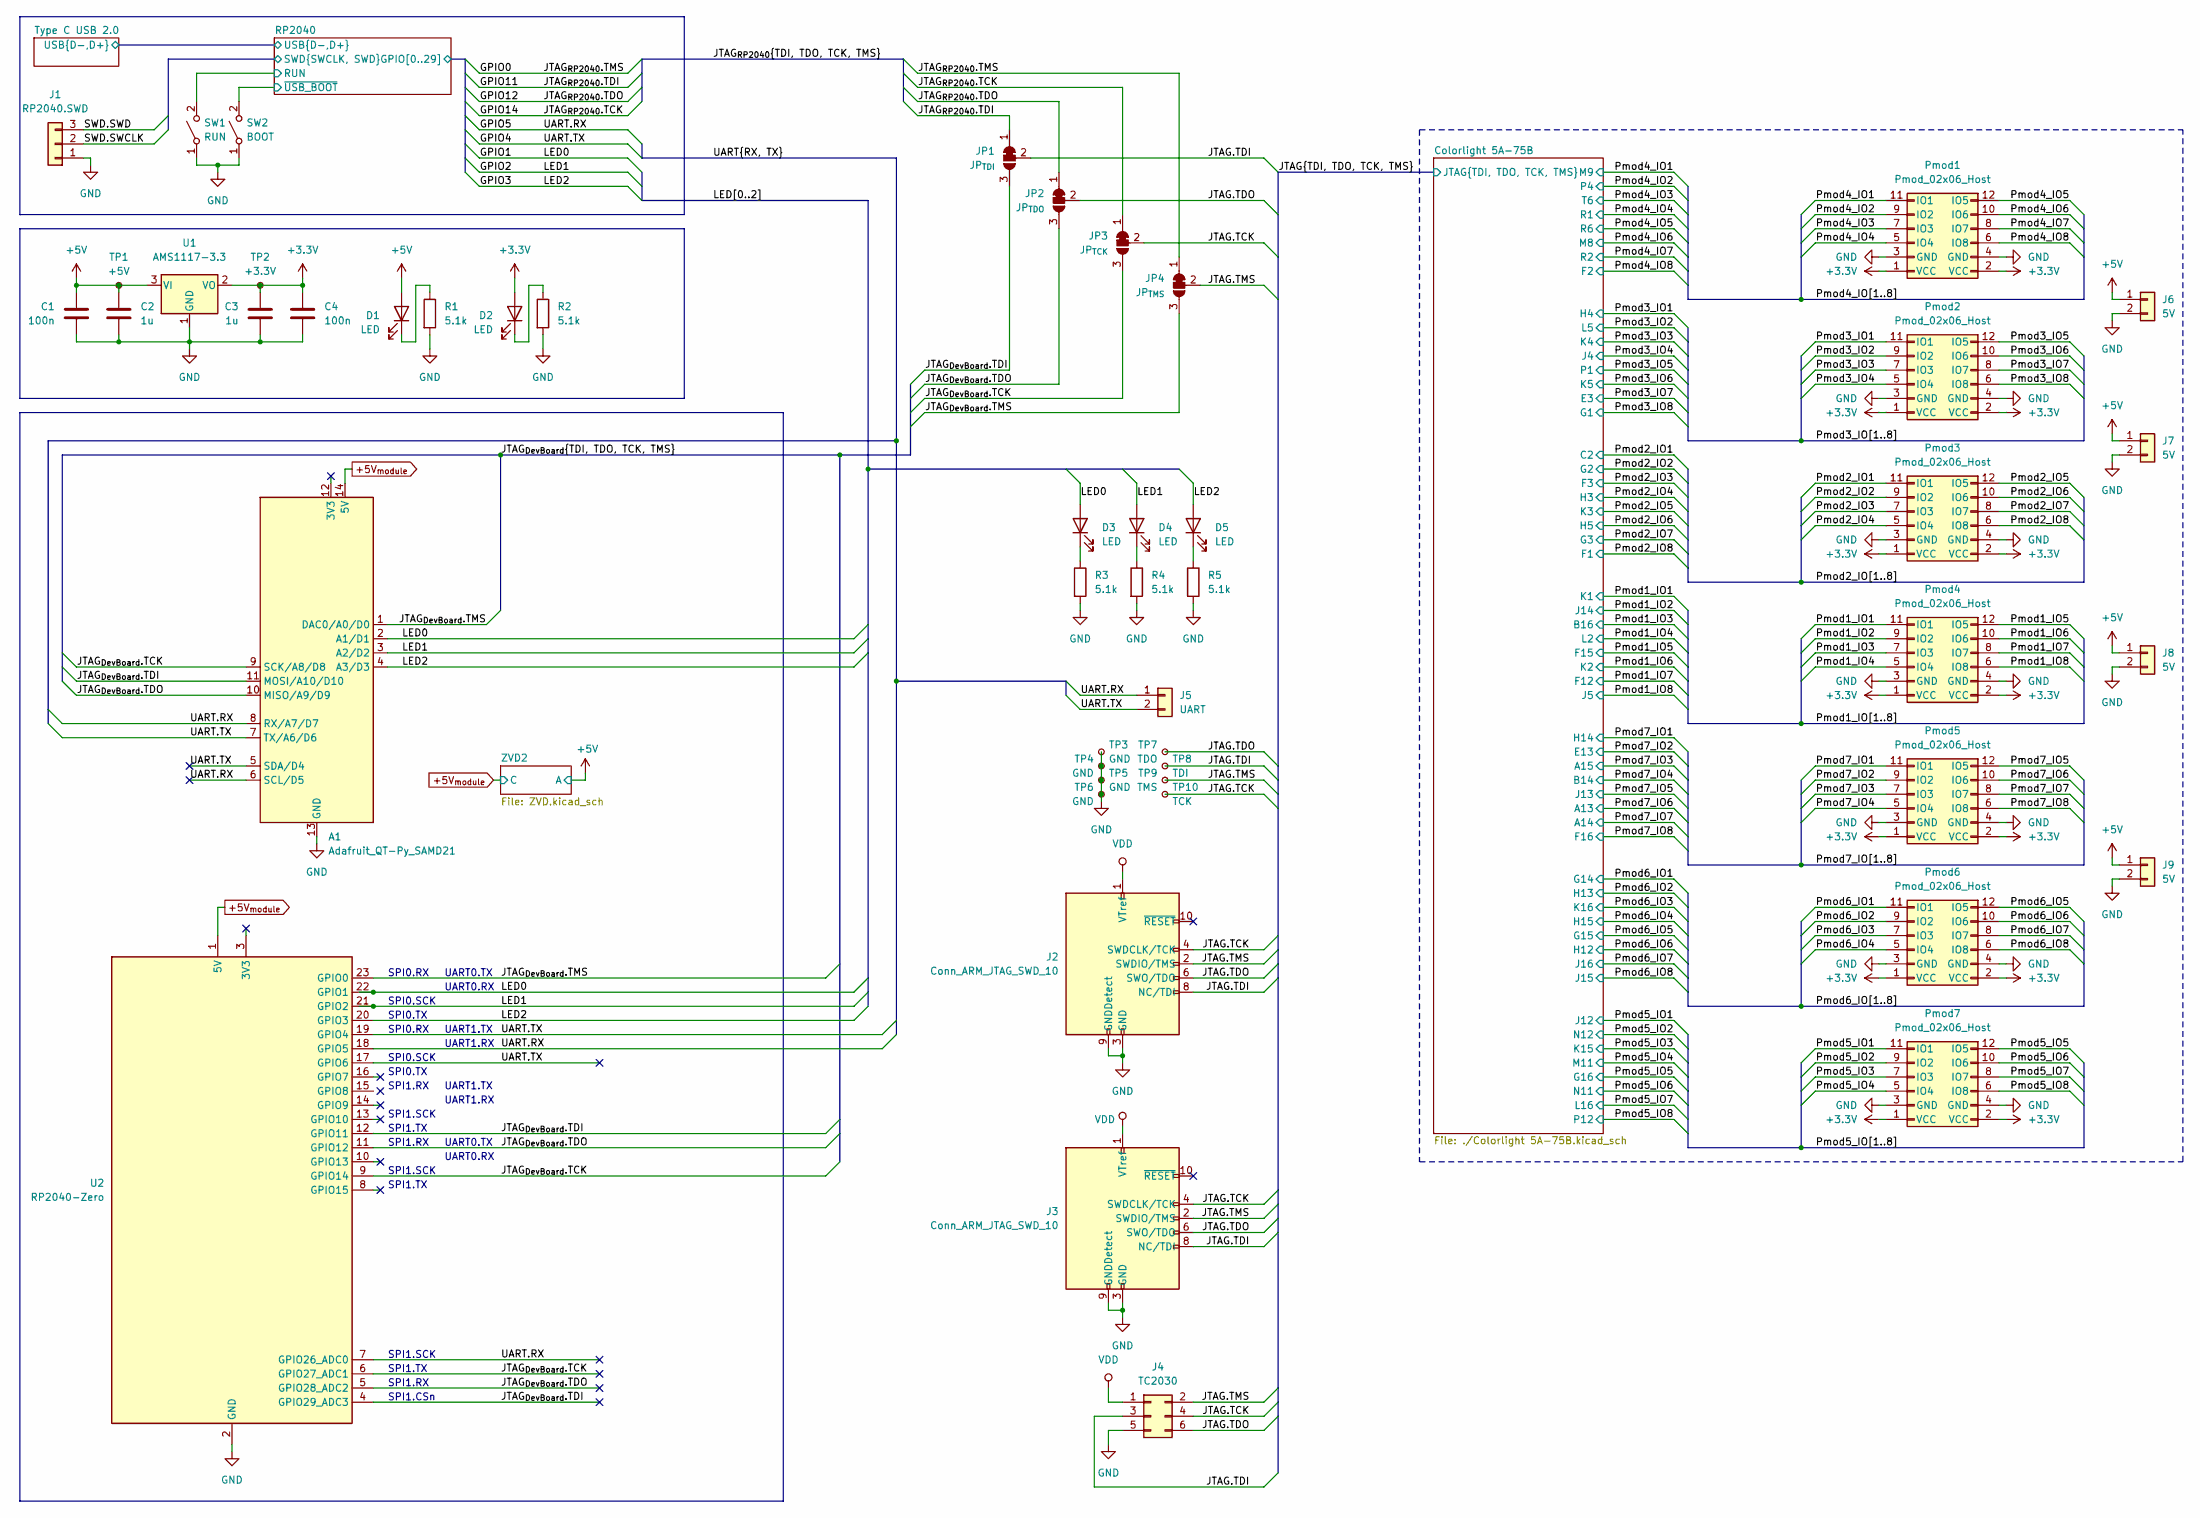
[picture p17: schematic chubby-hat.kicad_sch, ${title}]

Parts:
A1: Adafruit_QT-Py_SAMD21; QT-Py
C1, C4: 100n; C_0603_1608Metric
C2, C3: 1u; C_0603_1608Metric
D1, D2, D3, D4, D5: LED; LED_0603_1608Metric
J1: RP2040.SWD; PinHeader_1x03_P2.54mm_Vertical
J2: Conn_ARM_JTAG_SWD_10; IDC-Header_2x05_P2.54mm_Vertical
J3: Conn_ARM_JTAG_SWD_10; PinHeader_2x05_P1.27mm_Vertical
J4: TC2030; Tag-Connect_TC2030-IDC-FP_2x03_P1.27mm_Vertical
J5: UART; SolderWire-0.1sqmm_1x02_P3.6mm_D0.4mm_OD1mm_Relief2x
J6, J7, J8, J9: 5V; PinSocket_1x02_P2.54mm_Vertical
JP1: JP_{TDI}; SolderJumper-3_P1.3mm_Bridged12_RoundedPad1.0x1.5mm
JP2: JP_{TDO}; SolderJumper-3_P1.3mm_Bridged12_RoundedPad1.0x1.5mm
JP3: JP_{TCK}; SolderJumper-3_P1.3mm_Bridged12_RoundedPad1.0x1.5mm
JP4: JP_{TMS}; SolderJumper-3_P1.3mm_Bridged12_RoundedPad1.0x1.5mm
Pmod1, Pmod2, Pmod3, Pmod4, Pmod5, Pmod6, Pmod7: Pmod_02x06_Host; PinSocket_2x06_P2.54mm_Horizontal
R1, R2, R3, R4, R5: 5.1k; R_0603_1608Metric
SW1: RUN; SW_Push_1P1T_NO_6x6mm_H9.5mm
SW2: BOOT; SW_Push_1P1T_NO_6x6mm_H9.5mm
TP1: +5V; TestPoint_Pad_D1.0mm
TP2: +3.3V; TestPoint_Pad_D1.0mm
TP3, TP4, TP5, TP6: GND; TestPoint_Pad_D1.0mm
TP7: TDO; TestPoint_Pad_D1.0mm
TP8: TDI; TestPoint_Pad_D1.0mm
TP9: TMS; TestPoint_Pad_D1.0mm
TP10: TCK; TestPoint_Pad_D1.0mm
U1: AMS1117-3.3; SOT-223-3_TabPin2
U2: RP2040-Zero

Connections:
+5V: C1.2, C2.2, D1.2 (A), J6.1, J7.1, J8.1, J9.1, TP1.1, U1.3 (VI); also elsewhere on the board
+5V_{module}: A1.14 (5V), U2.1 (5V); also elsewhere on the board
/JTAG.TCK: J2.4 (SWDCLK/TCK), J3.4 (SWDCLK/TCK), J4.4, JP3.2 (C), TP10.1; also elsewhere on the board
/JTAG.TDI: J2.8 (NC/TDI), J3.8 (NC/TDI), J4.3, JP1.2 (C), TP8.1; also elsewhere on the board
/JTAG.TDO: J2.6 (SWO/TDO), J3.6 (SWO/TDO), J4.6, JP2.2 (C), TP7.1; also elsewhere on the board
/JTAG.TMS: J2.2 (SWDIO/TMS), J3.2 (SWDIO/TMS), J4.2, JP4.2 (C), TP9.1; also elsewhere on the board
/JTAG_{DevBoard}.TCK: A1.9 (SCK/A8/D8), JP3.3 (B), U2.6 (GPIO27_ADC1), U2.9 (GPIO14); also elsewhere on the board
/JTAG_{DevBoard}.TDI: A1.11 (MOSI/A10/D10), JP1.3 (B), U2.4 (GPIO29_ADC3), U2.12 (GPIO11); also elsewhere on the board
/JTAG_{DevBoard}.TDO: A1.10 (MISO/A9/D9), JP2.3 (B), U2.5 (GPIO28_ADC2), U2.11 (GPIO12); also elsewhere on the board
/JTAG_{DevBoard}.TMS: A1.1 (DAC0/A0/D0), JP4.3 (B), U2.23 (GPIO0); also elsewhere on the board
/Pmod1_IO1: Pmod4.11 (IO1); also elsewhere on the board
/Pmod1_IO2: Pmod4.9 (IO2); also elsewhere on the board
/Pmod1_IO3: Pmod4.7 (IO3); also elsewhere on the board
/Pmod1_IO4: Pmod4.5 (IO4); also elsewhere on the board
/Pmod1_IO5: Pmod4.12 (IO5); also elsewhere on the board
/Pmod1_IO6: Pmod4.10 (IO6); also elsewhere on the board
/Pmod1_IO7: Pmod4.8 (IO7); also elsewhere on the board
/Pmod1_IO8: Pmod4.6 (IO8); also elsewhere on the board
/Pmod2_IO1: Pmod3.11 (IO1); also elsewhere on the board
/Pmod2_IO2: Pmod3.9 (IO2); also elsewhere on the board
/Pmod2_IO3: Pmod3.7 (IO3); also elsewhere on the board
/Pmod2_IO4: Pmod3.5 (IO4); also elsewhere on the board
/Pmod2_IO5: Pmod3.12 (IO5); also elsewhere on the board
/Pmod2_IO6: Pmod3.10 (IO6); also elsewhere on the board
/Pmod2_IO7: Pmod3.8 (IO7); also elsewhere on the board
/Pmod2_IO8: Pmod3.6 (IO8); also elsewhere on the board
/Pmod3_IO1: Pmod2.11 (IO1); also elsewhere on the board
/Pmod3_IO2: Pmod2.9 (IO2); also elsewhere on the board
/Pmod3_IO3: Pmod2.7 (IO3); also elsewhere on the board
/Pmod3_IO4: Pmod2.5 (IO4); also elsewhere on the board
/Pmod3_IO5: Pmod2.12 (IO5); also elsewhere on the board
/Pmod3_IO6: Pmod2.10 (IO6); also elsewhere on the board
/Pmod3_IO7: Pmod2.8 (IO7); also elsewhere on the board
/Pmod3_IO8: Pmod2.6 (IO8); also elsewhere on the board
/Pmod4_IO1: Pmod1.11 (IO1); also elsewhere on the board
/Pmod4_IO2: Pmod1.9 (IO2); also elsewhere on the board
/Pmod4_IO3: Pmod1.7 (IO3); also elsewhere on the board
/Pmod4_IO4: Pmod1.5 (IO4); also elsewhere on the board
/Pmod4_IO5: Pmod1.12 (IO5); also elsewhere on the board
/Pmod4_IO6: Pmod1.10 (IO6); also elsewhere on the board
/Pmod4_IO7: Pmod1.8 (IO7); also elsewhere on the board
/Pmod4_IO8: Pmod1.6 (IO8); also elsewhere on the board
/Pmod5_IO1: Pmod7.11 (IO1); also elsewhere on the board
/Pmod5_IO2: Pmod7.9 (IO2); also elsewhere on the board
/Pmod5_IO3: Pmod7.7 (IO3); also elsewhere on the board
/Pmod5_IO4: Pmod7.5 (IO4); also elsewhere on the board
/Pmod5_IO5: Pmod7.12 (IO5); also elsewhere on the board
/Pmod5_IO6: Pmod7.10 (IO6); also elsewhere on the board
/Pmod5_IO7: Pmod7.8 (IO7); also elsewhere on the board
/Pmod5_IO8: Pmod7.6 (IO8); also elsewhere on the board
/Pmod6_IO1: Pmod6.11 (IO1); also elsewhere on the board
/Pmod6_IO2: Pmod6.9 (IO2); also elsewhere on the board
/Pmod6_IO3: Pmod6.7 (IO3); also elsewhere on the board
/Pmod6_IO4: Pmod6.5 (IO4); also elsewhere on the board
/Pmod6_IO5: Pmod6.12 (IO5); also elsewhere on the board
/Pmod6_IO6: Pmod6.10 (IO6); also elsewhere on the board
/Pmod6_IO7: Pmod6.8 (IO7); also elsewhere on the board
/Pmod6_IO8: Pmod6.6 (IO8); also elsewhere on the board
/Pmod7_IO1: Pmod5.11 (IO1); also elsewhere on the board
/Pmod7_IO2: Pmod5.9 (IO2); also elsewhere on the board
/Pmod7_IO3: Pmod5.7 (IO3); also elsewhere on the board
/Pmod7_IO4: Pmod5.5 (IO4); also elsewhere on the board
/Pmod7_IO5: Pmod5.12 (IO5); also elsewhere on the board
/Pmod7_IO6: Pmod5.10 (IO6); also elsewhere on the board
/Pmod7_IO7: Pmod5.8 (IO7); also elsewhere on the board
/Pmod7_IO8: Pmod5.6 (IO8); also elsewhere on the board
/RP2040/GPIO1: A1.2 (A1/D1), D3.2 (A), U2.22 (GPIO1); also elsewhere on the board
/RP2040/GPIO2: A1.3 (A2/D2), D4.2 (A), U2.21 (GPIO2); also elsewhere on the board
/RP2040/GPIO3: A1.4 (A3/D3), D5.2 (A), U2.20 (GPIO3); also elsewhere on the board
/RP2040/GPIO4: A1.5 (SDA/D4), A1.7 (TX/A6/D6), J5.2, U2.17 (GPIO6), U2.19 (GPIO4); also elsewhere on the board
/RP2040/GPIO5: A1.6 (SCL/D5), A1.8 (RX/A7/D7), J5.1, U2.7 (GPIO26_ADC0), U2.18 (GPIO5); also elsewhere on the board
/RP2040/RUN: SW1.2 (B); also elsewhere on the board
/RP2040/SWD.SWCLK: J1.2; also elsewhere on the board
/RP2040/SWD.SWD: J1.3; also elsewhere on the board
/RP2040/~USB_BOOT: SW2.2 (B); also elsewhere on the board
GND: A1.13 (GND), C1.1, C2.1, C3.1, C4.1, J1.1, J2.3 (GND), J2.5 (GND), J2.9 (GNDDetect), J3.3 (GND), J3.5 (GND), J3.9 (GNDDetect), J4.5, J6.2, J7.2, J8.2, J9.2, Pmod1.3 (GND), Pmod1.4 (GND), Pmod2.3 (GND), Pmod2.4 (GND), Pmod3.3 (GND), Pmod3.4 (GND), Pmod4.3 (GND), Pmod4.4 (GND), Pmod5.3 (GND), Pmod5.4 (GND), Pmod6.3 (GND), Pmod6.4 (GND), Pmod7.3 (GND), Pmod7.4 (GND), R1.2, R2.2, R3.2, R4.2, R5.2, SW1.1 (A), SW2.1 (A), TP3.1, TP4.1, TP5.1, TP6.1, U1.1 (GND), U2.2 (GND); also elsewhere on the board
unnamed: D1.1 (K), R1.1
unnamed: D2.1 (K), R2.1
unnamed: D3.1 (K), R3.1
unnamed: D4.1 (K), R4.1
unnamed: D5.1 (K), R5.1
VDD: J2.1 (VTref), J3.1 (VTref), J4.1; also elsewhere on the board

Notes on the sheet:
SPI1.TX
SPI0.SCK
UART0.TX
UART1.RX
UART1.TX
SPI1.CSn
UART0.RX
SPI1.RX
SPI0.RX
SPI1.SCK
SPI0.TX

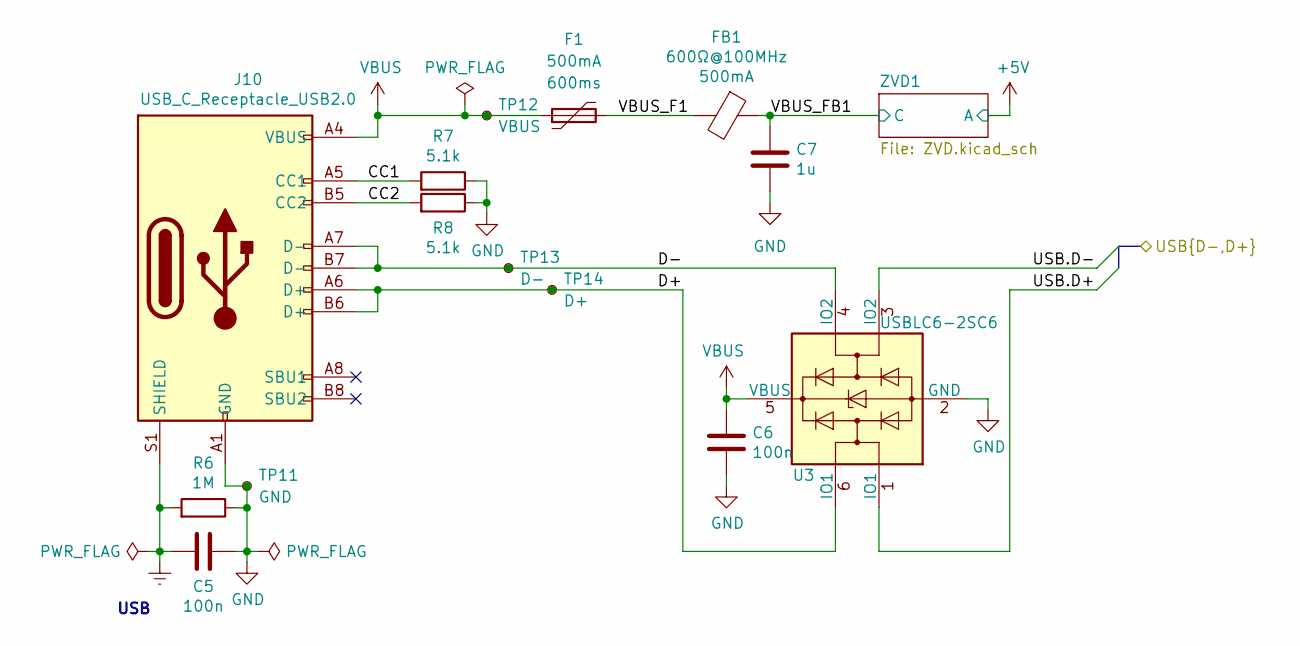
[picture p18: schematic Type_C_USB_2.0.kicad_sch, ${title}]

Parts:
C5, C6: 100n; C_0603_1608Metric
C7: 1u; C_0603_1608Metric
F1: 500mA; R_0603_1608Metric; MPN TLC-FSMD020; LCSC C261935
FB1: 600Ω@100MHz; L_0603_1608Metric; MPN FCM1608KF-601T05
J10: USB_C_Receptacle_USB2.0; USB_C_Receptacle_HRO_TYPE-C-31-D-09
R6: 1M; R_0603_1608Metric
R7, R8: 5.1k; R_0603_1608Metric
TP11: GND; TestPoint_Pad_D1.0mm
TP12: VBUS; TestPoint_Pad_D1.0mm
TP13: D-; TestPoint_Pad_D1.0mm
TP14: D+; TestPoint_Pad_D1.0mm
U3: USBLC6-2SC6; SOT-23-6

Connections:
/RP2040/USB.D+: U3.1 (IO1); also elsewhere on the board
/RP2040/USB.D-: U3.3 (IO2); also elsewhere on the board
/Type C USB 2.0/CC1: J10.A5 (CC1), R7.2
/Type C USB 2.0/CC2: J10.B5 (CC2), R8.2
/Type C USB 2.0/D+: J10.A6 (D+), J10.B6 (D+), TP14.1, U3.6 (IO1)
/Type C USB 2.0/D-: J10.A7 (D-), J10.B7 (D-), TP13.1, U3.4 (IO2)
/Type C USB 2.0/VBUS_F1: F1.2, FB1.2
/Type C USB 2.0/VBUS_FB1: C7.2, FB1.1; also elsewhere on the board
Earth: C5.1, J10.S1 (SHIELD), R6.2
GND: C5.2, C6.1, C7.1, J10.A1 (GND), J10.A12 (GND), J10.B1 (GND), J10.B12 (GND), R6.1, R7.1, R8.1, TP11.1, U3.2 (GND); also elsewhere on the board
VBUS: C6.2, F1.1, J10.A4 (VBUS), J10.A9 (VBUS), J10.B4 (VBUS), J10.B9 (VBUS), TP12.1, U3.5 (VBUS)

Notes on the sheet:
USB

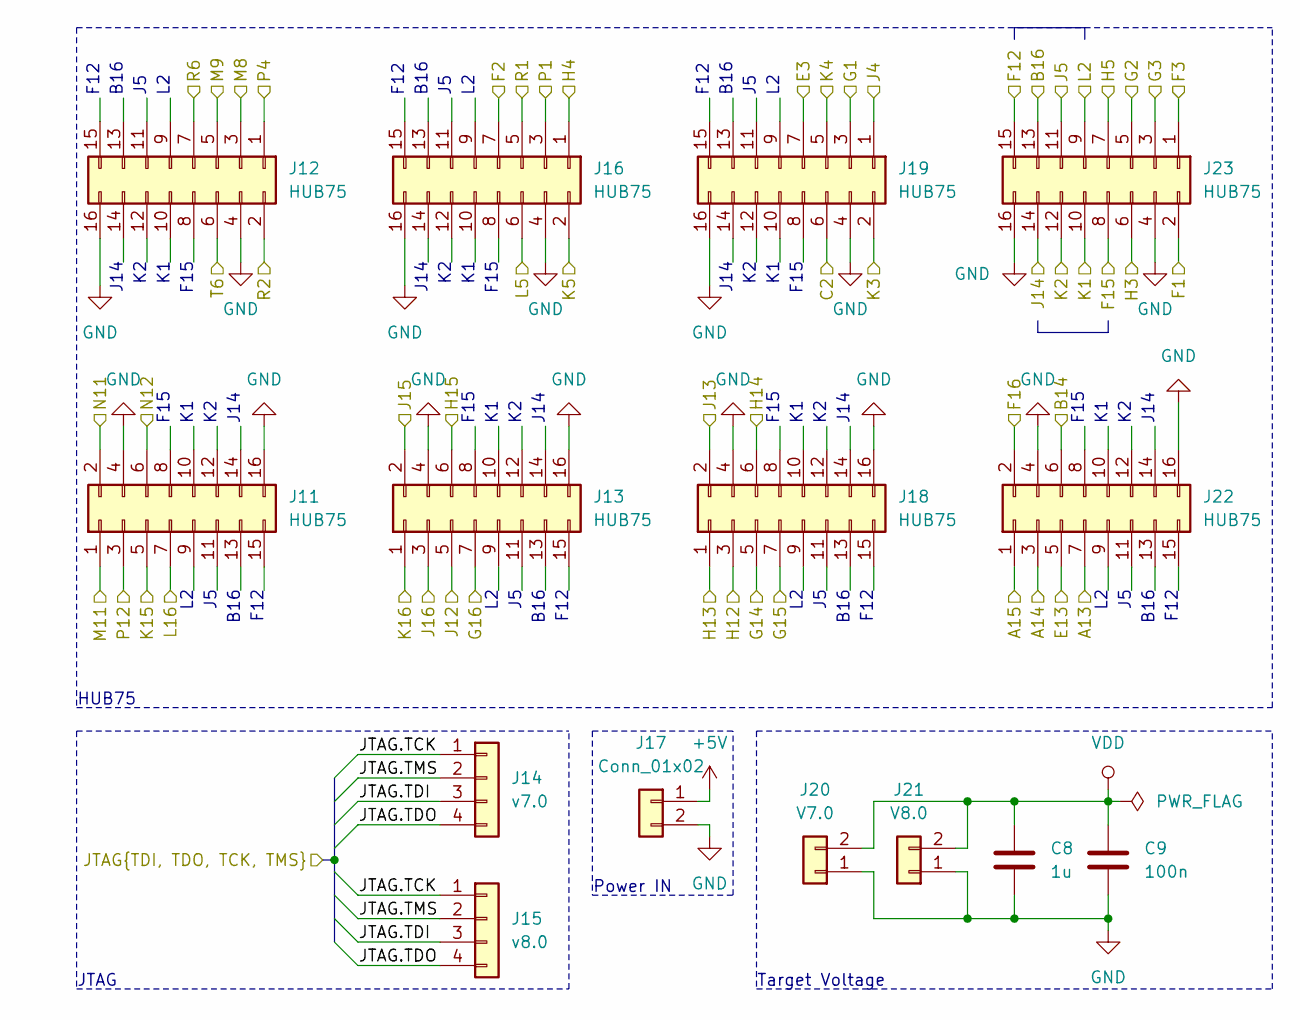
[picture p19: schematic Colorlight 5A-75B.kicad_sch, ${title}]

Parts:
C8: 1u; C_0603_1608Metric
C9: 100n; C_0603_1608Metric
J11, J12, J13, J16, J18, J19, J22, J23: HUB75; PinSocket_2x08_P2.54mm_Vertical
J14: v7.0; PinHeader_1x04_P2.54mm_Vertical
J15: v8.0; PinHeader_1x04_P2.54mm_Vertical
J17: Conn_01x02; SolderWire-0.5sqmm_1x02_P4.6mm_D0.9mm_OD2.1mm_Relief
J20: V7.0; PinHeader_1x02_P2.54mm_Vertical
J21: V8.0; PinHeader_1x02_P2.54mm_Vertical

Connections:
+5V: J17.1; also elsewhere on the board
/JTAG.TCK: J14.1, J15.1; also elsewhere on the board
/JTAG.TDI: J14.3, J15.3; also elsewhere on the board
/JTAG.TDO: J14.4, J15.4; also elsewhere on the board
/JTAG.TMS: J14.2, J15.2; also elsewhere on the board
/Pmod1_IO1: J23.10; also elsewhere on the board
/Pmod1_IO2: J23.14; also elsewhere on the board
/Pmod1_IO3: J23.13; also elsewhere on the board
/Pmod1_IO4: J23.9; also elsewhere on the board
/Pmod1_IO5: J23.8; also elsewhere on the board
/Pmod1_IO6: J23.12; also elsewhere on the board
/Pmod1_IO7: J23.15; also elsewhere on the board
/Pmod1_IO8: J23.11; also elsewhere on the board
/Pmod2_IO1: J19.6; also elsewhere on the board
/Pmod2_IO2: J23.5; also elsewhere on the board
/Pmod2_IO3: J23.1; also elsewhere on the board
/Pmod2_IO4: J23.6; also elsewhere on the board
/Pmod2_IO5: J19.2; also elsewhere on the board
/Pmod2_IO6: J23.7; also elsewhere on the board
/Pmod2_IO7: J23.3; also elsewhere on the board
/Pmod2_IO8: J23.2; also elsewhere on the board
/Pmod3_IO1: J16.1; also elsewhere on the board
/Pmod3_IO2: J16.6; also elsewhere on the board
/Pmod3_IO3: J19.5; also elsewhere on the board
/Pmod3_IO4: J19.1; also elsewhere on the board
/Pmod3_IO5: J16.3; also elsewhere on the board
/Pmod3_IO6: J16.2; also elsewhere on the board
/Pmod3_IO7: J19.7; also elsewhere on the board
/Pmod3_IO8: J19.3; also elsewhere on the board
/Pmod4_IO1: J12.5; also elsewhere on the board
/Pmod4_IO2: J12.1; also elsewhere on the board
/Pmod4_IO3: J12.6; also elsewhere on the board
/Pmod4_IO4: J16.5; also elsewhere on the board
/Pmod4_IO5: J12.7; also elsewhere on the board
/Pmod4_IO6: J12.3; also elsewhere on the board
/Pmod4_IO7: J12.2; also elsewhere on the board
/Pmod4_IO8: J16.7; also elsewhere on the board
/Pmod5_IO1: J13.5; also elsewhere on the board
/Pmod5_IO2: J11.6; also elsewhere on the board
/Pmod5_IO3: J11.5; also elsewhere on the board
/Pmod5_IO4: J11.1; also elsewhere on the board
/Pmod5_IO5: J13.7; also elsewhere on the board
/Pmod5_IO6: J11.2; also elsewhere on the board
/Pmod5_IO7: J11.7; also elsewhere on the board
/Pmod5_IO8: J11.3; also elsewhere on the board
/Pmod6_IO1: J18.5; also elsewhere on the board
/Pmod6_IO2: J18.1; also elsewhere on the board
/Pmod6_IO3: J13.1; also elsewhere on the board
/Pmod6_IO4: J13.6; also elsewhere on the board
/Pmod6_IO5: J18.7; also elsewhere on the board
/Pmod6_IO6: J18.3; also elsewhere on the board
/Pmod6_IO7: J13.3; also elsewhere on the board
/Pmod6_IO8: J13.2; also elsewhere on the board
/Pmod7_IO1: J18.6; also elsewhere on the board
/Pmod7_IO2: J22.5; also elsewhere on the board
/Pmod7_IO3: J22.1; also elsewhere on the board
/Pmod7_IO4: J22.6; also elsewhere on the board
/Pmod7_IO5: J18.2; also elsewhere on the board
/Pmod7_IO6: J22.7; also elsewhere on the board
/Pmod7_IO7: J22.3; also elsewhere on the board
/Pmod7_IO8: J22.2; also elsewhere on the board
GND: C8.1, C9.1, J11.4, J11.16, J12.4, J12.16, J13.4, J13.16, J16.4, J16.16, J17.2, J18.4, J18.16, J19.4, J19.16, J20.1, J21.1, J22.4, J22.16, J23.4, J23.16; also elsewhere on the board
VDD: C8.2, C9.2, J20.2, J21.2; also elsewhere on the board

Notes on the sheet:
J14
Target Voltage
F12
B16
HUB75
F15
Power IN
JTAG

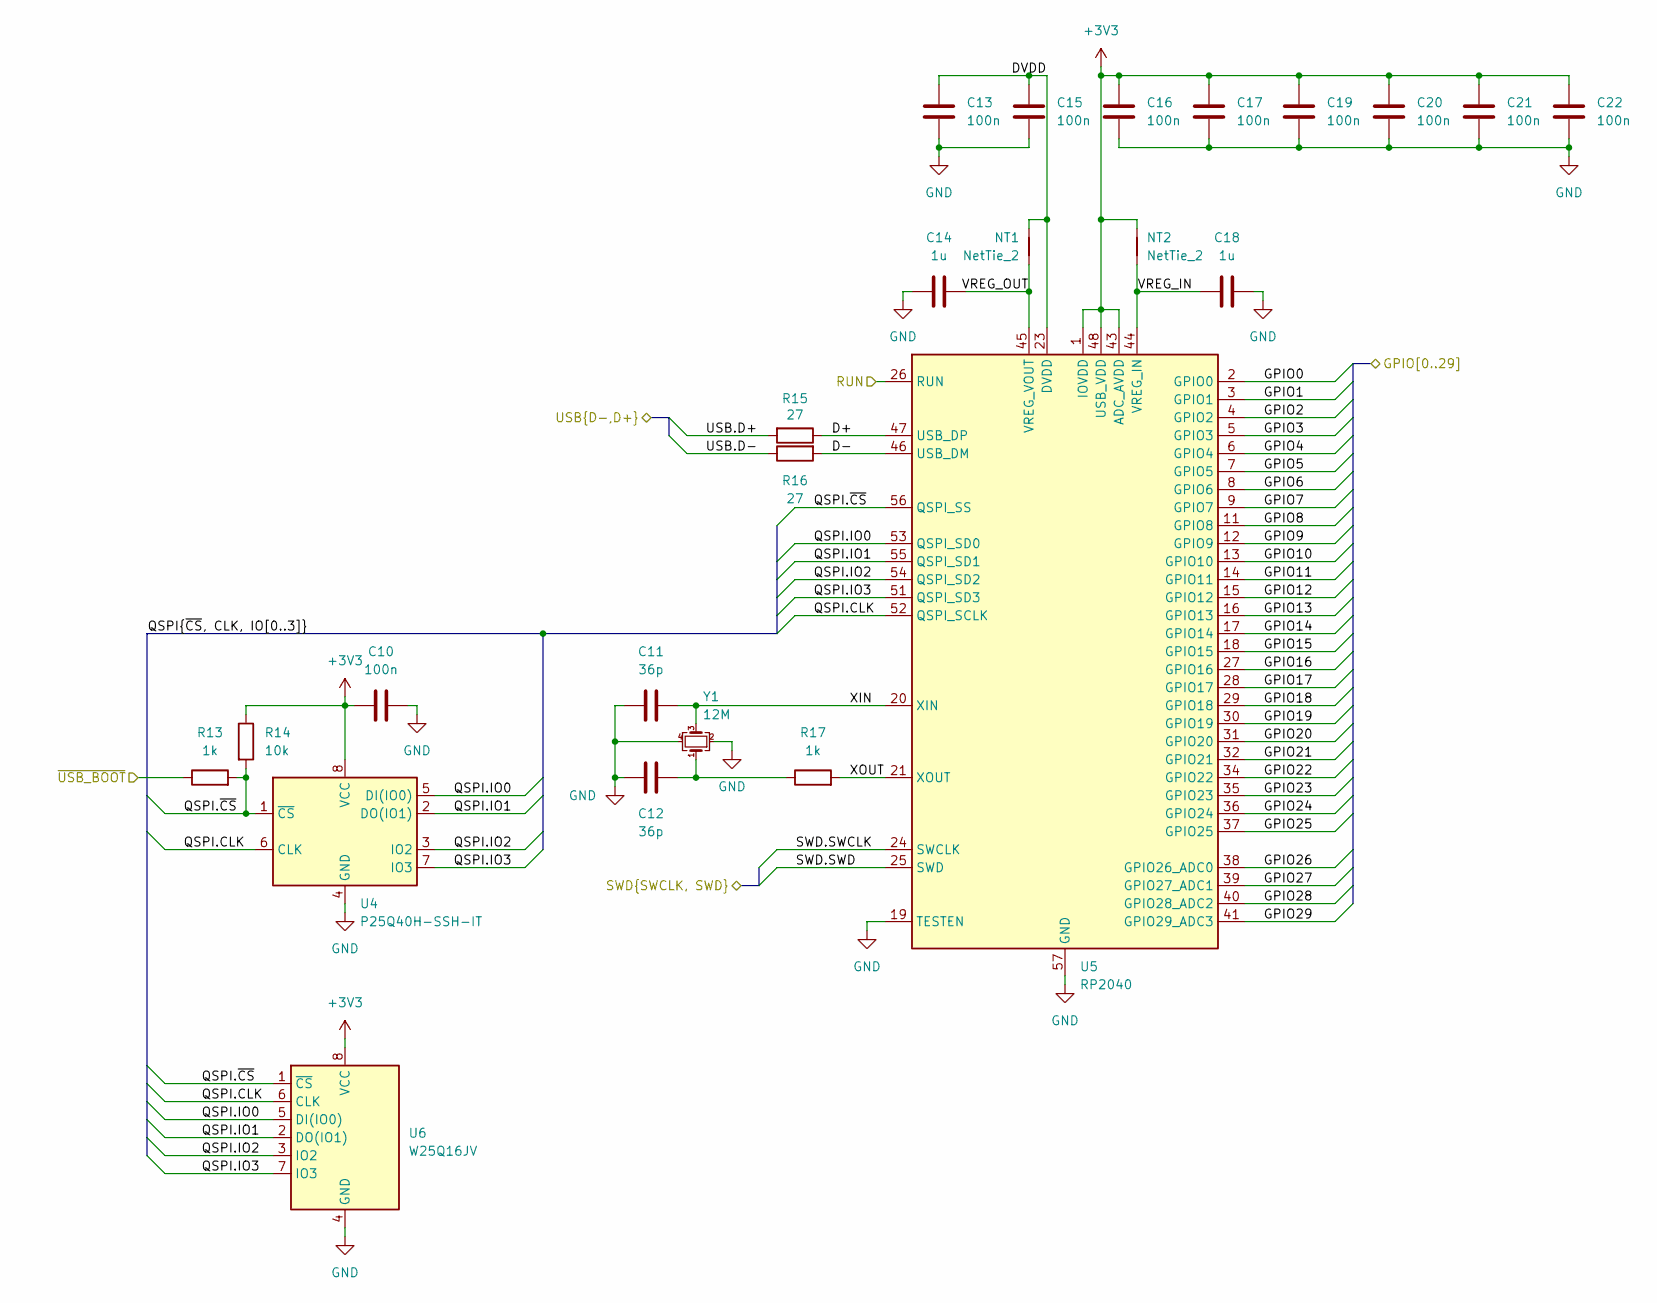
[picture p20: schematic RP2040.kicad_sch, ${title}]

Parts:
C10, C13, C15, C16, C17, C19, C20, C21, C22: 100n; C_0603_1608Metric
C11, C12: 36p; C_0603_1608Metric
C14, C18: 1u; C_0603_1608Metric
NT1, NT2: NetTie_2; NetTie-2_SMD_Pad0.5mm
R13, R17: 1k; R_0603_1608Metric
R14: 10k; R_0603_1608Metric
R15, R16: 27; R_0603_1608Metric
U4: P25Q40H-SSH-IT; SOIC-8_5.23x5.23mm_P1.27mm
U5: RP2040; QFN-56-1EP_7x7mm_P0.4mm_EP3.2x3.2mm
U6: W25Q16JV; VSSOP-8_2.3x2mm_P0.5mm
Y1: 12M; Crystal_SMD_3225-4Pin_3.2x2.5mm; MPN X322512MSB4SI

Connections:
/RP2040/D+: R15.1, U5.47 (USB_DP)
/RP2040/D-: R16.2, U5.46 (USB_DM)
/RP2040/DVDD: C13.1, C15.1, NT1.2, U5.23 (DVDD), U5.50 (DVDD)
/RP2040/GPIO0: U5.2 (GPIO0); also elsewhere on the board
/RP2040/GPIO1: U5.3 (GPIO1); also elsewhere on the board
/RP2040/GPIO2: U5.4 (GPIO2); also elsewhere on the board
/RP2040/GPIO3: U5.5 (GPIO3); also elsewhere on the board
/RP2040/GPIO4: U5.6 (GPIO4); also elsewhere on the board
/RP2040/GPIO5: U5.7 (GPIO5); also elsewhere on the board
/RP2040/GPIO6: U5.8 (GPIO6)
/RP2040/GPIO7: U5.9 (GPIO7)
/RP2040/GPIO8: U5.11 (GPIO8)
/RP2040/GPIO9: U5.12 (GPIO9)
/RP2040/GPIO10: U5.13 (GPIO10)
/RP2040/GPIO11: U5.14 (GPIO11); also elsewhere on the board
/RP2040/GPIO12: U5.15 (GPIO12); also elsewhere on the board
/RP2040/GPIO13: U5.16 (GPIO13)
/RP2040/GPIO14: U5.17 (GPIO14); also elsewhere on the board
/RP2040/GPIO15: U5.18 (GPIO15)
/RP2040/GPIO16: U5.27 (GPIO16)
/RP2040/GPIO17: U5.28 (GPIO17)
/RP2040/GPIO18: U5.29 (GPIO18)
/RP2040/GPIO19: U5.30 (GPIO19)
/RP2040/GPIO20: U5.31 (GPIO20)
/RP2040/GPIO21: U5.32 (GPIO21)
/RP2040/GPIO22: U5.34 (GPIO22)
/RP2040/GPIO23: U5.35 (GPIO23)
/RP2040/GPIO24: U5.36 (GPIO24)
/RP2040/GPIO25: U5.37 (GPIO25)
/RP2040/GPIO26: U5.38 (GPIO26_ADC0)
/RP2040/GPIO27: U5.39 (GPIO27_ADC1)
/RP2040/GPIO28: U5.40 (GPIO28_ADC2)
/RP2040/GPIO29: U5.41 (GPIO29_ADC3)
/RP2040/QSPI.CLK: U4.6 (CLK), U5.52 (QSPI_SCLK), U6.6 (CLK)
/RP2040/QSPI.IO0: U4.5 (DI(IO0)), U5.53 (QSPI_SD0), U6.5 (DI(IO0))
/RP2040/QSPI.IO1: U4.2 (DO(IO1)), U5.55 (QSPI_SD1), U6.2 (DO(IO1))
/RP2040/QSPI.IO2: U4.3 (IO2), U5.54 (QSPI_SD2), U6.3 (IO2)
/RP2040/QSPI.IO3: U4.7 (IO3), U5.51 (QSPI_SD3), U6.7 (IO3)
/RP2040/QSPI.~CS: R13.2, R14.2, U4.1 (~CS), U5.56 (QSPI_SS), U6.1 (~CS)
/RP2040/RUN: U5.26 (RUN); also elsewhere on the board
/RP2040/SWD.SWCLK: U5.24 (SWCLK); also elsewhere on the board
/RP2040/SWD.SWD: U5.25 (SWD); also elsewhere on the board
/RP2040/USB.D+: R15.2; also elsewhere on the board
/RP2040/USB.D-: R16.1; also elsewhere on the board
/RP2040/VREG_IN: C18.1, NT2.2, U5.44 (VREG_IN)
/RP2040/VREG_OUT: C14.1, NT1.1, U5.45 (VREG_VOUT)
/RP2040/XIN: C11.1, U5.20 (XIN), Y1.3
/RP2040/XOUT: R17.2, U5.21 (XOUT)
/RP2040/~USB_BOOT: R13.1; also elsewhere on the board
GND: C10.2, C11.2, C12.2, C13.2, C14.2, C15.2, C16.2, C17.2, C18.2, C19.2, C20.2, C21.2, C22.2, U4.4 (GND), U5.19 (TESTEN), U5.57 (GND), U6.4 (GND), Y1.2, Y1.4; also elsewhere on the board
unnamed: C12.1, R17.1, Y1.1

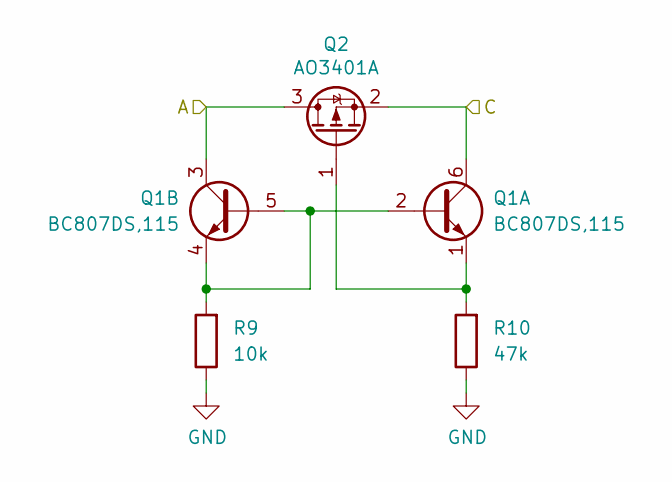
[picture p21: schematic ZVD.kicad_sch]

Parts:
Q1: BC807DS,115; SC-74-6_1.5x2.9mm_P0.95mm
Q2: AO3401A; SOT-23
R9: 10k; R_0603_1608Metric
R10: 47k; R_0603_1608Metric

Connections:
+5V: Q1.3 (C2), Q2.3 (D); also elsewhere on the board
/Type C USB 2.0/VBUS_FB1: Q1.6 (C1), Q2.2 (S); also elsewhere on the board
GND: R9.1, R10.1; also elsewhere on the board
unnamed: Q1.2 (B1), Q1.4 (E2), Q1.5 (B2), R9.2
unnamed: Q1.1 (E1), Q2.1 (G), R10.2

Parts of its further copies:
Q3: BC807DS,115; SC-74-6_1.5x2.9mm_P0.95mm
Q4: AO3401A; SOT-23
R11: 10k; R_0603_1608Metric
R12: 47k; R_0603_1608Metric

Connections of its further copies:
+5V: Q3.3 (C2), Q4.3 (D); also elsewhere on the board
+5V_{module}: Q3.6 (C1), Q4.2 (S); also elsewhere on the board
GND: R11.1, R12.1; also elsewhere on the board
unnamed: Q3.2 (B1), Q3.4 (E2), Q3.5 (B2), R11.2
unnamed: Q3.1 (E1), Q4.1 (G), R12.2

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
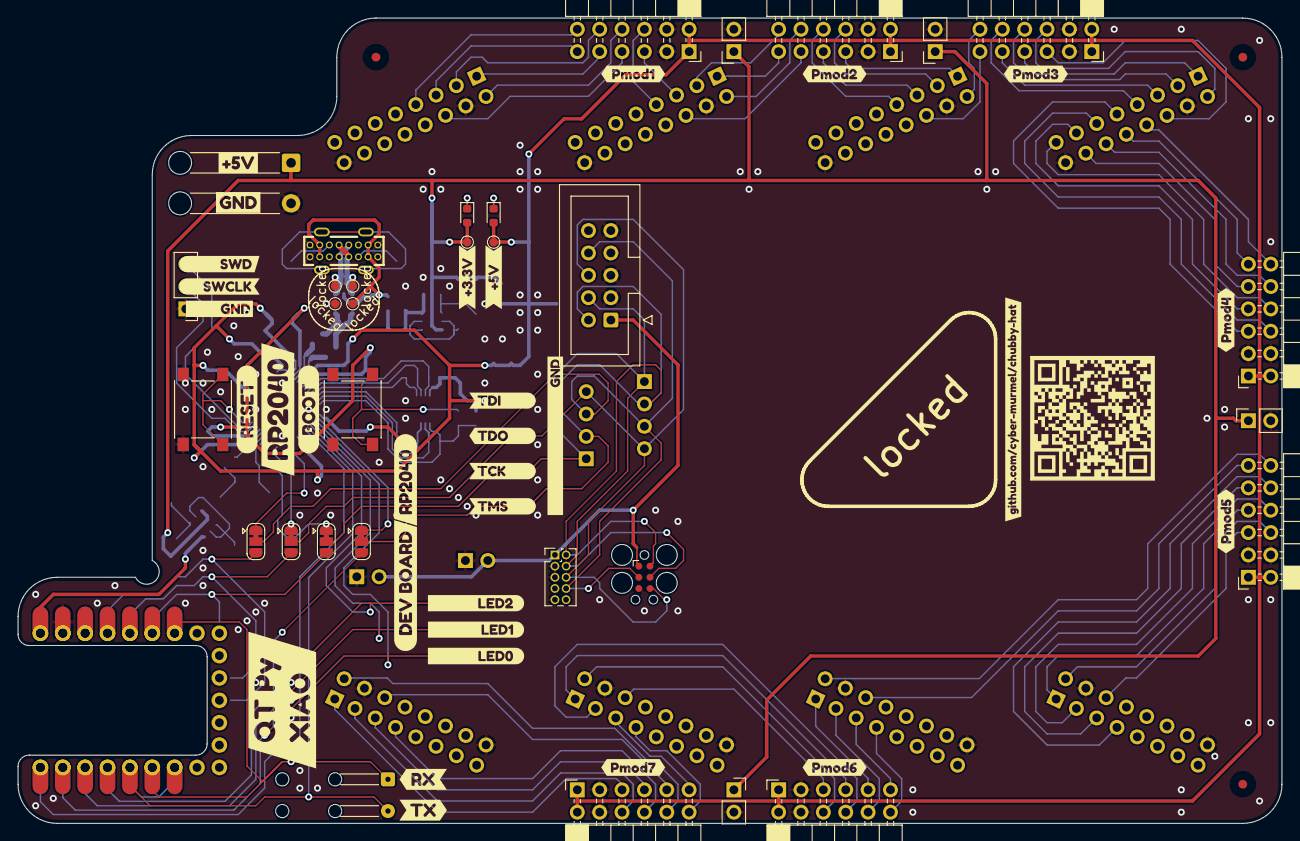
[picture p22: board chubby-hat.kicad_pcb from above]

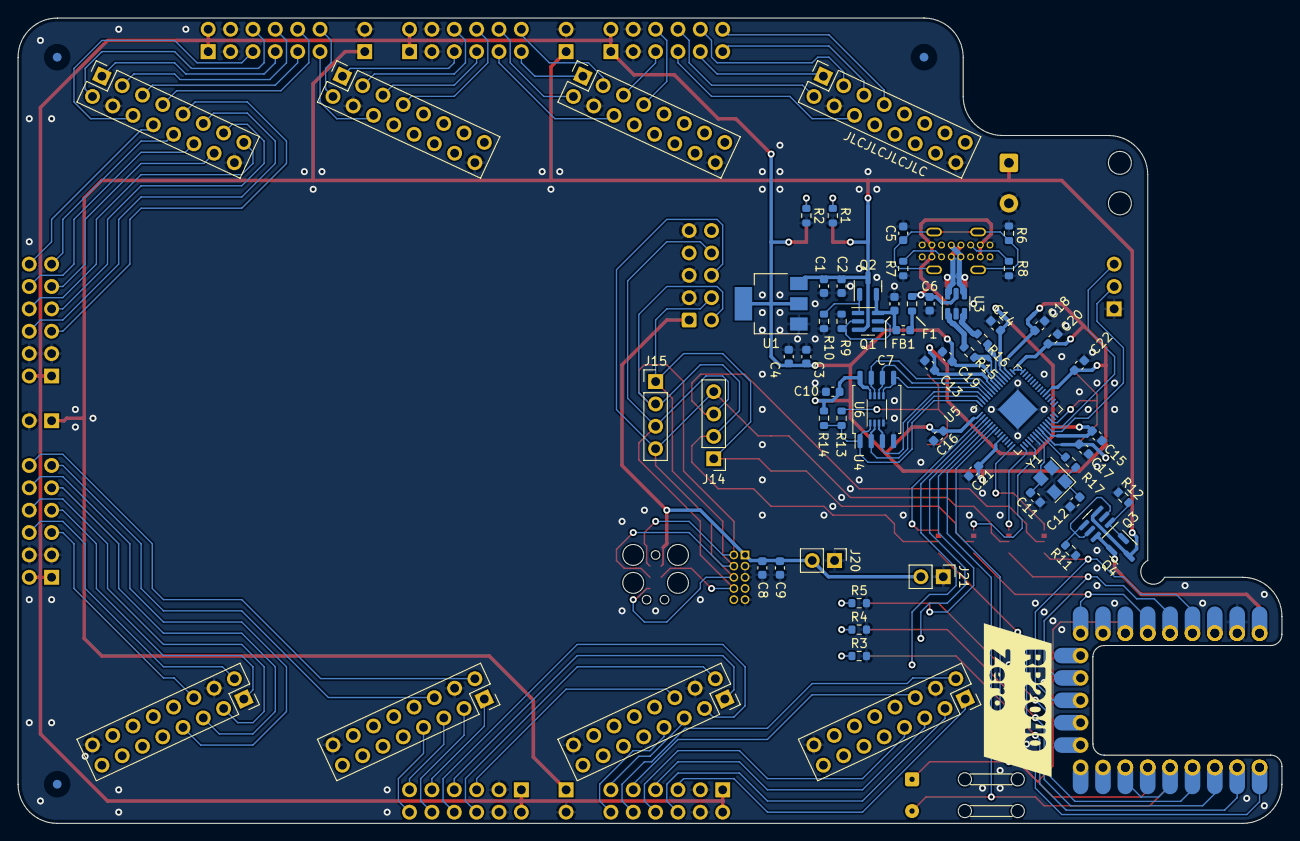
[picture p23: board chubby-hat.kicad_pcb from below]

Board: 2 copper layers, 143.5 x 91.4 mm, 143 parts (67 on the bottom side), 115 nets.

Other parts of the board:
QR*****: github.com/cyber-murmel/chubby-hat; github.com_cyber-murmel_chubby-hat
kibuzzard-63D6B6FA: G***; kibuzzard-63D6B6FA
kibuzzard-63D6B15C: G***; kibuzzard-63D6B15C
kibuzzard-63D6B25C: G***; kibuzzard-63D6B25C
kibuzzard-63D6B78A: G***; kibuzzard-63D6B78A
kibuzzard-63D6B79B: G***; kibuzzard-63D6B79B
kibuzzard-63D6B152: G***; kibuzzard-63D6B152
kibuzzard-63D6B171: G***; kibuzzard-63D6B171
kibuzzard-63D6B260: G***; kibuzzard-63D6B260
kibuzzard-63D6CBA0: G***; kibuzzard-63D6CBA0
kibuzzard-63D6CBB9: G***; kibuzzard-63D6CBB9
kibuzzard-63E6D9D7: G***; kibuzzard-63E6D9D7
kibuzzard-63E6D9E4: G***; kibuzzard-63E6D9E4
kibuzzard-63E6D9E9: G***; kibuzzard-63E6D9E9
kibuzzard-63E586AA: G***; kibuzzard-63E586AA
kibuzzard-63E586B9: G***; kibuzzard-63E586B9
kibuzzard-63E586CE: G***; kibuzzard-63E586CE
kibuzzard-63E586D5: G***; kibuzzard-63E586D5
kibuzzard-63E586DD: G***; kibuzzard-63E586DD
kibuzzard-63E586E8: G***; kibuzzard-63E586E8
kibuzzard-63E586F0: G***; kibuzzard-63E586F0
kibuzzard-63E664A0: G***; kibuzzard-63E664A0
kibuzzard-63E664C7: G***; kibuzzard-63E664C7
kibuzzard-63E664D7: G***; kibuzzard-63E664D7
kibuzzard-63E665A8: G***; kibuzzard-63E665A8
kibuzzard-63E665B7: G***; kibuzzard-63E665B7
kibuzzard-63E5252B: G***; kibuzzard-63E5252B
kibuzzard-63E5830C: G***; kibuzzard-63E5830C
kibuzzard-63E5907B: G***; kibuzzard-63E5907B
kibuzzard-63E58302: G***; kibuzzard-63E58302
kibuzzard-63E58321: G***; kibuzzard-63E58321
kibuzzard-63E66495: G***; kibuzzard-63E66495
kibuzzard-63E67724: G***; kibuzzard-63E67724
locked: JP_{TDO}; SolderJumper-3_P1.3mm_Bridged12_RoundedPad1.0x1.5mm
locked#2: JP_{TMS}; SolderJumper-3_P1.3mm_Bridged12_RoundedPad1.0x1.5mm
locked#3: JP_{TDI}; SolderJumper-3_P1.3mm_Bridged12_RoundedPad1.0x1.5mm
locked#4: JP_{TCK}; SolderJumper-3_P1.3mm_Bridged12_RoundedPad1.0x1.5mm

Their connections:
/JTAG.TCK: locked#4.2 (C); also elsewhere on the board
/JTAG.TDI: locked#3.2 (C); also elsewhere on the board
/JTAG.TDO: locked.2 (C); also elsewhere on the board
/JTAG.TMS: locked#2.2 (C); also elsewhere on the board
/JTAG_{DevBoard}.TCK: locked#4.3 (B); also elsewhere on the board
/JTAG_{DevBoard}.TDI: locked#3.3 (B); also elsewhere on the board
/JTAG_{DevBoard}.TDO: locked.3 (B); also elsewhere on the board
/JTAG_{DevBoard}.TMS: locked#2.3 (B); also elsewhere on the board
/RP2040/GPIO0: locked#2.1 (A); also elsewhere on the board
/RP2040/GPIO11: locked#3.1 (A); also elsewhere on the board
/RP2040/GPIO12: locked.1 (A); also elsewhere on the board
/RP2040/GPIO14: locked#4.1 (A); also elsewhere on the board

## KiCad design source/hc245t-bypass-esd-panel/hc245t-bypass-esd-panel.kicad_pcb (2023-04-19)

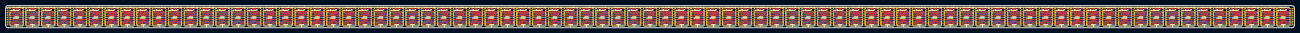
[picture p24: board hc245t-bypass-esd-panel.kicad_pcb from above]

Board: 2 copper layers, 466.0 x 8.0 mm, 405 parts (0 on the bottom side), 11 nets.

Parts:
C1, C2, C3, C4, C5, C6, C7, C8, C9, C10, C11, C12, C13, C14, C15, C16, C17, C18, C19, C20, C21, C22, C23, C24, C25, C26, C27, C28, C29, C30, C31, C32, C33, C34, C35, C36, C37, C38, C39, C40, C41, C42, C43, C44, C45, C46, C47, C48, C49, C50, C51, C52, C53, C54, C55, C56, C57, C58, C59, C60, C61, C62, C63, C64, C65, C66, C67, C68, C69, C70, C71, C72, C73, C74, C75, C76, C77, C78, C79, C80, C81: C; C_0402_1005Metric
R1, R2, R3, R4, R5, R6, R7, R8, R9, R10, R11, R12, R13, R14, R15, R16, R17, R18, R19, R20, R21, R22, R23, R24, R25, R26, R27, R28, R29, R30, R31, R32, R33, R34, R35, R36, R37, R38, R39, R40, R41, R42, R43, R44, R45, R46, R47, R48, R49, R50, R51, R52, R53, R54, R55, R56, R57, R58, R59, R60, R61, R62, R63, R64, R65, R66, R67, R68, R69, R70, R71, R72, R73, R74, R75, R76, R77, R78, R79, R80, R81: R; R_0402_1005Metric
U1, U4, U7, U10, U13, U16, U19, U22, U25, U28, U31, U34, U37, U40, U43, U46, U49, U52, U55, U58, U61, U64, U67, U70, U73, U76, U79, U82, U85, U88, U91, U94, U97, U100, U103, U106, U109, U112, U115, U118, U121, U124, U127, U130, U133, U136, U139, U142, U145, U148, U151, U154, U157, U160, U163, U166, U169, U172, U175, U178, U181, U184, U187, U190, U193, U196, U199, U202, U205, U208, U211, U214, U217, U220, U223, U226, U229, U232, U235, U238, U241: 74HC245; TSSOP-20_4.4x6.5mm_P0.65mm
U2, U3, U5, U6, U8, U9, U11, U12, U14, U15, U17, U18, U20, U21, U23, U24, U26, U27, U29, U30, U32, U33, U35, U36, U38, U39, U41, U42, U44, U45, U47, U48, U50, U51, U53, U54, U56, U57, U59, U60, U62, U63, U65, U66, U68, U69, U71, U72, U74, U75, U77, U78, U80, U81, U83, U84, U86, U87, U89, U90, U92, U93, U95, U96, U98, U99, U101, U102, U104, U105, U107, U108, U110, U111, U113, U114, U116, U117, U119, U120, U122, U123, U125, U126, U128, U129, U131, U132, U134, U135, U137, U138, U140, U141, U143, U144, U146, U147, U149, U150, U152, U153, U155, U156, U158, U159, U161, U162, U164, U165, U167, U168, U170, U171, U173, U174, U176, U177, U179, U180, U182, U183, U185, U186, U188, U189, U191, U192, U194, U195, U197, U198, U200, U201, U203, U204, U206, U207, U209, U210, U212, U213, U215, U216, U218, U219, U221, U222, U224, U225, U227, U228, U230, U231, U233, U234, U236, U237, U239, U240, U242, U243: NUP4202; SOT-363_SC-70-6

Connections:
/D0: U1.2 (A0), U1.18 (B0), U2.6, U4.2 (A0), U4.18 (B0), U5.6, U7.2 (A0), U7.18 (B0), U8.6, U10.2 (A0), U10.18 (B0), U11.6, U13.2 (A0), U13.18 (B0), U14.6, U16.2 (A0), U16.18 (B0), U17.6, U19.2 (A0), U19.18 (B0), U20.6, U22.2 (A0), U22.18 (B0), U23.6, U25.2 (A0), U25.18 (B0), U26.6, U28.2 (A0), U28.18 (B0), U29.6, U31.2 (A0), U31.18 (B0), U32.6, U34.2 (A0), U34.18 (B0), U35.6, U37.2 (A0), U37.18 (B0), U38.6, U40.2 (A0), U40.18 (B0), U41.6, U43.2 (A0), U43.18 (B0), U44.6, U46.2 (A0), U46.18 (B0), U47.6, U49.2 (A0), U49.18 (B0), U50.6, U52.2 (A0), U52.18 (B0), U53.6, U55.2 (A0), U55.18 (B0), U56.6, U58.2 (A0), U58.18 (B0), U59.6, U61.2 (A0), U61.18 (B0), U62.6, U64.2 (A0), U64.18 (B0), U65.6, U67.2 (A0), U67.18 (B0), U68.6, U70.2 (A0), U70.18 (B0), U71.6, U73.2 (A0), U73.18 (B0), U74.6, U76.2 (A0), U76.18 (B0), U77.6, U79.2 (A0), U79.18 (B0), U80.6, U82.2 (A0), U82.18 (B0), U83.6, U85.2 (A0), U85.18 (B0), U86.6, U88.2 (A0), U88.18 (B0), U89.6, U91.2 (A0), U91.18 (B0), U92.6, U94.2 (A0), U94.18 (B0), U95.6, U97.2 (A0), U97.18 (B0), U98.6, U100.2 (A0), U100.18 (B0), U101.6, U103.2 (A0), U103.18 (B0), U104.6, U106.2 (A0), U106.18 (B0), U107.6, U109.2 (A0), U109.18 (B0), U110.6, U112.2 (A0), U112.18 (B0), U113.6, U115.2 (A0), U115.18 (B0), U116.6, U118.2 (A0), U118.18 (B0), U119.6, U121.2 (A0), U121.18 (B0), U122.6, U124.2 (A0), U124.18 (B0), U125.6, U127.2 (A0), U127.18 (B0), U128.6, U130.2 (A0), U130.18 (B0), U131.6, U133.2 (A0), U133.18 (B0), U134.6, U136.2 (A0), U136.18 (B0), U137.6, U139.2 (A0), U139.18 (B0), U140.6, U142.2 (A0), U142.18 (B0), U143.6, U145.2 (A0), U145.18 (B0), U146.6, U148.2 (A0), U148.18 (B0), U149.6, U151.2 (A0), U151.18 (B0), U152.6, U154.2 (A0), U154.18 (B0), U155.6, U157.2 (A0), U157.18 (B0), U158.6, U160.2 (A0), U160.18 (B0), U161.6, U163.2 (A0), U163.18 (B0), U164.6, U166.2 (A0), U166.18 (B0), U167.6, U169.2 (A0), U169.18 (B0), U170.6, U172.2 (A0), U172.18 (B0), U173.6, U175.2 (A0), U175.18 (B0), U176.6, U178.2 (A0), U178.18 (B0), U179.6, U181.2 (A0), U181.18 (B0), U182.6, U184.2 (A0), U184.18 (B0), U185.6, U187.2 (A0), U187.18 (B0), U188.6, U190.2 (A0), U190.18 (B0), U191.6, U193.2 (A0), U193.18 (B0), U194.6, U196.2 (A0), U196.18 (B0), U197.6, U199.2 (A0), U199.18 (B0), U200.6, U202.2 (A0), U202.18 (B0), U203.6, U205.2 (A0), U205.18 (B0), U206.6, U208.2 (A0), U208.18 (B0), U209.6, U211.2 (A0), U211.18 (B0), U212.6, U214.2 (A0), U214.18 (B0), U215.6, U217.2 (A0), U217.18 (B0), U218.6, U220.2 (A0), U220.18 (B0), U221.6, U223.2 (A0), U223.18 (B0), U224.6, U226.2 (A0), U226.18 (B0), U227.6, U229.2 (A0), U229.18 (B0), U230.6, U232.2 (A0), U232.18 (B0), U233.6, U235.2 (A0), U235.18 (B0), U236.6, U238.2 (A0), U238.18 (B0), U239.6, U241.2 (A0), U241.18 (B0), U242.6
/D1: U1.3 (A1), U1.17 (B1), U2.1, U4.3 (A1), U4.17 (B1), U5.1, U7.3 (A1), U7.17 (B1), U8.1, U10.3 (A1), U10.17 (B1), U11.1, U13.3 (A1), U13.17 (B1), U14.1, U16.3 (A1), U16.17 (B1), U17.1, U19.3 (A1), U19.17 (B1), U20.1, U22.3 (A1), U22.17 (B1), U23.1, U25.3 (A1), U25.17 (B1), U26.1, U28.3 (A1), U28.17 (B1), U29.1, U31.3 (A1), U31.17 (B1), U32.1, U34.3 (A1), U34.17 (B1), U35.1, U37.3 (A1), U37.17 (B1), U38.1, U40.3 (A1), U40.17 (B1), U41.1, U43.3 (A1), U43.17 (B1), U44.1, U46.3 (A1), U46.17 (B1), U47.1, U49.3 (A1), U49.17 (B1), U50.1, U52.3 (A1), U52.17 (B1), U53.1, U55.3 (A1), U55.17 (B1), U56.1, U58.3 (A1), U58.17 (B1), U59.1, U61.3 (A1), U61.17 (B1), U62.1, U64.3 (A1), U64.17 (B1), U65.1, U67.3 (A1), U67.17 (B1), U68.1, U70.3 (A1), U70.17 (B1), U71.1, U73.3 (A1), U73.17 (B1), U74.1, U76.3 (A1), U76.17 (B1), U77.1, U79.3 (A1), U79.17 (B1), U80.1, U82.3 (A1), U82.17 (B1), U83.1, U85.3 (A1), U85.17 (B1), U86.1, U88.3 (A1), U88.17 (B1), U89.1, U91.3 (A1), U91.17 (B1), U92.1, U94.3 (A1), U94.17 (B1), U95.1, U97.3 (A1), U97.17 (B1), U98.1, U100.3 (A1), U100.17 (B1), U101.1, U103.3 (A1), U103.17 (B1), U104.1, U106.3 (A1), U106.17 (B1), U107.1, U109.3 (A1), U109.17 (B1), U110.1, U112.3 (A1), U112.17 (B1), U113.1, U115.3 (A1), U115.17 (B1), U116.1, U118.3 (A1), U118.17 (B1), U119.1, U121.3 (A1), U121.17 (B1), U122.1, U124.3 (A1), U124.17 (B1), U125.1, U127.3 (A1), U127.17 (B1), U128.1, U130.3 (A1), U130.17 (B1), U131.1, U133.3 (A1), U133.17 (B1), U134.1, U136.3 (A1), U136.17 (B1), U137.1, U139.3 (A1), U139.17 (B1), U140.1, U142.3 (A1), U142.17 (B1), U143.1, U145.3 (A1), U145.17 (B1), U146.1, U148.3 (A1), U148.17 (B1), U149.1, U151.3 (A1), U151.17 (B1), U152.1, U154.3 (A1), U154.17 (B1), U155.1, U157.3 (A1), U157.17 (B1), U158.1, U160.3 (A1), U160.17 (B1), U161.1, U163.3 (A1), U163.17 (B1), U164.1, U166.3 (A1), U166.17 (B1), U167.1, U169.3 (A1), U169.17 (B1), U170.1, U172.3 (A1), U172.17 (B1), U173.1, U175.3 (A1), U175.17 (B1), U176.1, U178.3 (A1), U178.17 (B1), U179.1, U181.3 (A1), U181.17 (B1), U182.1, U184.3 (A1), U184.17 (B1), U185.1, U187.3 (A1), U187.17 (B1), U188.1, U190.3 (A1), U190.17 (B1), U191.1, U193.3 (A1), U193.17 (B1), U194.1, U196.3 (A1), U196.17 (B1), U197.1, U199.3 (A1), U199.17 (B1), U200.1, U202.3 (A1), U202.17 (B1), U203.1, U205.3 (A1), U205.17 (B1), U206.1, U208.3 (A1), U208.17 (B1), U209.1, U211.3 (A1), U211.17 (B1), U212.1, U214.3 (A1), U214.17 (B1), U215.1, U217.3 (A1), U217.17 (B1), U218.1, U220.3 (A1), U220.17 (B1), U221.1, U223.3 (A1), U223.17 (B1), U224.1, U226.3 (A1), U226.17 (B1), U227.1, U229.3 (A1), U229.17 (B1), U230.1, U232.3 (A1), U232.17 (B1), U233.1, U235.3 (A1), U235.17 (B1), U236.1, U238.3 (A1), U238.17 (B1), U239.1, U241.3 (A1), U241.17 (B1), U242.1
/D2: U1.4 (A2), U1.16 (B2), U2.4, U4.4 (A2), U4.16 (B2), U5.4, U7.4 (A2), U7.16 (B2), U8.4, U10.4 (A2), U10.16 (B2), U11.4, U13.4 (A2), U13.16 (B2), U14.4, U16.4 (A2), U16.16 (B2), U17.4, U19.4 (A2), U19.16 (B2), U20.4, U22.4 (A2), U22.16 (B2), U23.4, U25.4 (A2), U25.16 (B2), U26.4, U28.4 (A2), U28.16 (B2), U29.4, U31.4 (A2), U31.16 (B2), U32.4, U34.4 (A2), U34.16 (B2), U35.4, U37.4 (A2), U37.16 (B2), U38.4, U40.4 (A2), U40.16 (B2), U41.4, U43.4 (A2), U43.16 (B2), U44.4, U46.4 (A2), U46.16 (B2), U47.4, U49.4 (A2), U49.16 (B2), U50.4, U52.4 (A2), U52.16 (B2), U53.4, U55.4 (A2), U55.16 (B2), U56.4, U58.4 (A2), U58.16 (B2), U59.4, U61.4 (A2), U61.16 (B2), U62.4, U64.4 (A2), U64.16 (B2), U65.4, U67.4 (A2), U67.16 (B2), U68.4, U70.4 (A2), U70.16 (B2), U71.4, U73.4 (A2), U73.16 (B2), U74.4, U76.4 (A2), U76.16 (B2), U77.4, U79.4 (A2), U79.16 (B2), U80.4, U82.4 (A2), U82.16 (B2), U83.4, U85.4 (A2), U85.16 (B2), U86.4, U88.4 (A2), U88.16 (B2), U89.4, U91.4 (A2), U91.16 (B2), U92.4, U94.4 (A2), U94.16 (B2), U95.4, U97.4 (A2), U97.16 (B2), U98.4, U100.4 (A2), U100.16 (B2), U101.4, U103.4 (A2), U103.16 (B2), U104.4, U106.4 (A2), U106.16 (B2), U107.4, U109.4 (A2), U109.16 (B2), U110.4, U112.4 (A2), U112.16 (B2), U113.4, U115.4 (A2), U115.16 (B2), U116.4, U118.4 (A2), U118.16 (B2), U119.4, U121.4 (A2), U121.16 (B2), U122.4, U124.4 (A2), U124.16 (B2), U125.4, U127.4 (A2), U127.16 (B2), U128.4, U130.4 (A2), U130.16 (B2), U131.4, U133.4 (A2), U133.16 (B2), U134.4, U136.4 (A2), U136.16 (B2), U137.4, U139.4 (A2), U139.16 (B2), U140.4, U142.4 (A2), U142.16 (B2), U143.4, U145.4 (A2), U145.16 (B2), U146.4, U148.4 (A2), U148.16 (B2), U149.4, U151.4 (A2), U151.16 (B2), U152.4, U154.4 (A2), U154.16 (B2), U155.4, U157.4 (A2), U157.16 (B2), U158.4, U160.4 (A2), U160.16 (B2), U161.4, U163.4 (A2), U163.16 (B2), U164.4, U166.4 (A2), U166.16 (B2), U167.4, U169.4 (A2), U169.16 (B2), U170.4, U172.4 (A2), U172.16 (B2), U173.4, U175.4 (A2), U175.16 (B2), U176.4, U178.4 (A2), U178.16 (B2), U179.4, U181.4 (A2), U181.16 (B2), U182.4, U184.4 (A2), U184.16 (B2), U185.4, U187.4 (A2), U187.16 (B2), U188.4, U190.4 (A2), U190.16 (B2), U191.4, U193.4 (A2), U193.16 (B2), U194.4, U196.4 (A2), U196.16 (B2), U197.4, U199.4 (A2), U199.16 (B2), U200.4, U202.4 (A2), U202.16 (B2), U203.4, U205.4 (A2), U205.16 (B2), U206.4, U208.4 (A2), U208.16 (B2), U209.4, U211.4 (A2), U211.16 (B2), U212.4, U214.4 (A2), U214.16 (B2), U215.4, U217.4 (A2), U217.16 (B2), U218.4, U220.4 (A2), U220.16 (B2), U221.4, U223.4 (A2), U223.16 (B2), U224.4, U226.4 (A2), U226.16 (B2), U227.4, U229.4 (A2), U229.16 (B2), U230.4, U232.4 (A2), U232.16 (B2), U233.4, U235.4 (A2), U235.16 (B2), U236.4, U238.4 (A2), U238.16 (B2), U239.4, U241.4 (A2), U241.16 (B2), U242.4
/D3: U1.5 (A3), U1.15 (B3), U2.3, U4.5 (A3), U4.15 (B3), U5.3, U7.5 (A3), U7.15 (B3), U8.3, U10.5 (A3), U10.15 (B3), U11.3, U13.5 (A3), U13.15 (B3), U14.3, U16.5 (A3), U16.15 (B3), U17.3, U19.5 (A3), U19.15 (B3), U20.3, U22.5 (A3), U22.15 (B3), U23.3, U25.5 (A3), U25.15 (B3), U26.3, U28.5 (A3), U28.15 (B3), U29.3, U31.5 (A3), U31.15 (B3), U32.3, U34.5 (A3), U34.15 (B3), U35.3, U37.5 (A3), U37.15 (B3), U38.3, U40.5 (A3), U40.15 (B3), U41.3, U43.5 (A3), U43.15 (B3), U44.3, U46.5 (A3), U46.15 (B3), U47.3, U49.5 (A3), U49.15 (B3), U50.3, U52.5 (A3), U52.15 (B3), U53.3, U55.5 (A3), U55.15 (B3), U56.3, U58.5 (A3), U58.15 (B3), U59.3, U61.5 (A3), U61.15 (B3), U62.3, U64.5 (A3), U64.15 (B3), U65.3, U67.5 (A3), U67.15 (B3), U68.3, U70.5 (A3), U70.15 (B3), U71.3, U73.5 (A3), U73.15 (B3), U74.3, U76.5 (A3), U76.15 (B3), U77.3, U79.5 (A3), U79.15 (B3), U80.3, U82.5 (A3), U82.15 (B3), U83.3, U85.5 (A3), U85.15 (B3), U86.3, U88.5 (A3), U88.15 (B3), U89.3, U91.5 (A3), U91.15 (B3), U92.3, U94.5 (A3), U94.15 (B3), U95.3, U97.5 (A3), U97.15 (B3), U98.3, U100.5 (A3), U100.15 (B3), U101.3, U103.5 (A3), U103.15 (B3), U104.3, U106.5 (A3), U106.15 (B3), U107.3, U109.5 (A3), U109.15 (B3), U110.3, U112.5 (A3), U112.15 (B3), U113.3, U115.5 (A3), U115.15 (B3), U116.3, U118.5 (A3), U118.15 (B3), U119.3, U121.5 (A3), U121.15 (B3), U122.3, U124.5 (A3), U124.15 (B3), U125.3, U127.5 (A3), U127.15 (B3), U128.3, U130.5 (A3), U130.15 (B3), U131.3, U133.5 (A3), U133.15 (B3), U134.3, U136.5 (A3), U136.15 (B3), U137.3, U139.5 (A3), U139.15 (B3), U140.3, U142.5 (A3), U142.15 (B3), U143.3, U145.5 (A3), U145.15 (B3), U146.3, U148.5 (A3), U148.15 (B3), U149.3, U151.5 (A3), U151.15 (B3), U152.3, U154.5 (A3), U154.15 (B3), U155.3, U157.5 (A3), U157.15 (B3), U158.3, U160.5 (A3), U160.15 (B3), U161.3, U163.5 (A3), U163.15 (B3), U164.3, U166.5 (A3), U166.15 (B3), U167.3, U169.5 (A3), U169.15 (B3), U170.3, U172.5 (A3), U172.15 (B3), U173.3, U175.5 (A3), U175.15 (B3), U176.3, U178.5 (A3), U178.15 (B3), U179.3, U181.5 (A3), U181.15 (B3), U182.3, U184.5 (A3), U184.15 (B3), U185.3, U187.5 (A3), U187.15 (B3), U188.3, U190.5 (A3), U190.15 (B3), U191.3, U193.5 (A3), U193.15 (B3), U194.3, U196.5 (A3), U196.15 (B3), U197.3, U199.5 (A3), U199.15 (B3), U200.3, U202.5 (A3), U202.15 (B3), U203.3, U205.5 (A3), U205.15 (B3), U206.3, U208.5 (A3), U208.15 (B3), U209.3, U211.5 (A3), U211.15 (B3), U212.3, U214.5 (A3), U214.15 (B3), U215.3, U217.5 (A3), U217.15 (B3), U218.3, U220.5 (A3), U220.15 (B3), U221.3, U223.5 (A3), U223.15 (B3), U224.3, U226.5 (A3), U226.15 (B3), U227.3, U229.5 (A3), U229.15 (B3), U230.3, U232.5 (A3), U232.15 (B3), U233.3, U235.5 (A3), U235.15 (B3), U236.3, U238.5 (A3), U238.15 (B3), U239.3, U241.5 (A3), U241.15 (B3), U242.3
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

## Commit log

2022-05-17 make kicad version selection easier
2022-06-16 added empty project
    [kicad-template.kicad_pcb, kicad-template.kicad_sch]
2022-09-22 set pkgs to nixos-22.05-2022_08_27; updates kicad to 6.0.5
2022-09-22 add default text variables
    [kicad-template.kicad_pcb, kicad-template.kicad_sch]
2022-10-03 added OSH Park boards setups; moved template
    [2 layer.kicad_pcb, 4 layer.kicad_pcb, 6 layer.kicad_pcb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]
2022-10-03 make OSH Park 2 layer default
    [template.kicad_pcb]
2023-01-30 finished version 0.2.0
    [RP2040.kicad_sch, Type_C_USB_2.0.kicad_sch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]
2023-01-31 added connectors for v8.0; improved power layout
    [Colorlight 5A-75B.kicad_sch, RP2040.kicad_sch, Type_C_USB_2.0.kicad_sch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]
2023-02-08 switch P4 and R2 on HUB75 J4; closes #5
    [Colorlight 5A-75B.kicad_sch, chubby-hat.kicad_pcb, chubby-hat.kicad_sch]
2023-02-10 add test points and leds - closes #1; add fuse - closes #4; add silk screen art
    [Colorlight 5A-75B.kicad_sch, RP2040.kicad_sch, Type_C_USB_2.0.kicad_sch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]
2023-02-12 add zero volt diodes to USB and modules; add status LEDs; add RP2040 SWD - closes #9
    [Colorlight 5A-75B.kicad_sch, RP2040.kicad_sch, Type_C_USB_2.0.kicad_sch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]
2023-02-25 moved to KiCad v7.0.0
    [Colorlight 5A-75B.kicad_sch, RP2040.kicad_sch, Type_C_USB_2.0.kicad_sch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]
2023-02-25 rotated v8 jtag connector - closes #10; moved aux jtag connectors and pmod wires to makes space for #14;
    [chubby-hat.kicad_pcb]
2023-02-25 add USON-8 footprint for W25Q16JV style flash; closes #13
    [RP2040.kicad_sch, chubby-hat.kicad_pcb]
2023-03-18 add prototyping area; closes #14
    [RP2040.kicad_sch, Type_C_USB_2.0.kicad_sch, chubby-hat.kicad_sch]
2023-03-19 automate export and pattern creation
    [chubby-hat-B.Cu.gbr, chubby-hat-B.Mask.gbr, chubby-hat-B.Paste.gbr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]
2023-03-19 bump kicad to 7.0.1
2023-03-20 copy from template
    [chubby-hat-B.Cu.gbr, chubby-hat-B.Mask.gbr, chubby-hat-B.Paste.gbr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]
2023-03-20 increase pmod labels; closes #15
    [chubby-hat-B.Cu.gbr, chubby-hat-B.Mask.gbr, chubby-hat-B.Paste.gbr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]
2023-04-19 remade hc245t bypass panel
    [chubby-hat-B.Cu.gbr, chubby-hat-B.Mask.gbr, chubby-hat-B.Paste.gbr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]
